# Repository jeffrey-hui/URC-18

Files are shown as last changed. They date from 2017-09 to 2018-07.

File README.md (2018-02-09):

# URC-18

Hello there! Welcome to the URC-18 github repository. Here is where all the URC code for 2018 is see teamr3/URC for 2017.
The file structure of this repo is fairly simple:

| File/Directory | Purpose |
| :--- | ---: |
| rosws | contains all the packages we have written in ros, packages that are deps should either be done with wstool or rosdep |
| scripts | contains various scripts to make things easier |
| microcontroller | contains platformio projects for each microcontroller |
| pcbs | contains PCB eagle design files |

## getting setup

To get setup, do the following:

1. Clone this repository

...Make sure you put it somewhere memorable, you're going to be cd-ing to it a lot.

2. From the *root* of the repo, run `scripts/setup.sh`

...The script will ask you about some things, and might prompt you to install some stuff.
...Once it's done, it'll build everything. If this fails, it probably just means we have some bad code checked in.

3. That's it!

## requirements

- a working ROS install, currently we're using kinetic.

# branches

In order to ensure working code on the master branch, keep new features/packages on their own branches. If you are re-writing something, make a new branch for the rewrite, and
base new packages off of that branch. For example:

```
+-- master
    + -- science-excel
    + -- new-auto
         + -- move_base_config
    + -- ros_control
         + new_arm
         + new_drive
```

---
*Master should always be good working code*
---

When a feature/bugfix is done on a branch, it can be merged to its parent. For example, if `new_arm` in the example was done, it would get merged to `ros_control`. When all of `ros_control` is done, it
gets merged to master. Try and use pull requests for bigger merges, especially when re-writing large portions of existing code.

# documentation

The decision has been made to use readthedocs, the url is r3-urc18.readthedocs.io.
Documentation is in the docs/ folder. Information on how to document is coming soon

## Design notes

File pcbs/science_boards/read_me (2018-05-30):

//TODO:
-Add optocouplers for all digital sensors, refer to main board for optocoupler
and the required passives (attempt to find the surface mount version of the
optocoupler used on the main board)
-Add 7V supply for annemometor
-decoupling capacitors for all supply lines
-bidirectional logic level converter for i2c, refer to battery boards
for how to do this (Ask Gabe if you cant figure it out)
-arbitrary analog and digital inputs
//NOTE:
-1206 series 
-HCPL0500
-Molex Mini Fit Jr.

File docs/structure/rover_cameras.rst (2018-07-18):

=============
rover_cameras
=============

The rover_cameras package contains the launch files and code to handle the rover's cameras.

There is one launch file to launch all the camera nodes. This also contains the camera switcher node.

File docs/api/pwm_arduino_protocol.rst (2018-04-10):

====================
Arduino Protocol (eml_uberdriver)
====================

The eml_uberdriver protocol documentation is now hosted elsewhere due to it being a seperate library.

Find it here: http://r3enamel.readthedocs.io/en/latest

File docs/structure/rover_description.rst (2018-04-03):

=================
rover_description
=================

The rover_description package contains all the urdf related things. It's a quite simple package
There is only one special folder in it, ``urdf``

--------
``urdf``
--------

In here are all the xacro files for the rover urdf. Attachments like the arm or autonomous should be put in separate files and be parametrized
so that different robot configurations are easily modeled.

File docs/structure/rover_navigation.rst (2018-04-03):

================
rover_navigation
================

``rover_navigation`` is our implementation / configuration of a move_base stack.

.. note:
   Although this file does document how to change the auton parameters, for general usage you should probably just start the launch file
   as described in the usage docs.

----------
``config``
----------

The config folder contains all of the yaml configuration for ``move_base``. There are three files in it.

``planner.yaml``
================

``planner.yaml`` contains all of the configuration for the planners (global and local). For documentation on what the parameters in it mean,
see the docs for ``base_local_planner`` and ``navfn``.

``local_costmap.yaml`` and ``global_costmap.yaml``
==================================================

These files contain the configuration for the local and global costmaps respectively. The documentation for them is in the `costmap_2d` package.

---------------------
Internal Launch Files
---------------------

Although the usage documentation only details one launch file, there are a lot of internal ones with more parametrization.

``move_base.launch``
====================

The ``move_base.launch`` file contains the launch spec for starting move_base itself. It contains two useful parameters, located on lines 6 and 7:

.. code-block:: xml
   :lineno-start: 6
        <param name="base_global_planner" value="global_planner/GlobalPlanner" />
        <param name="base_local_planner" value="base_local_planner/TrajectoryPlannerROS" />

This sets the ``base_(global/local)_planner``.

``odometry.launch``
===================

This is one of the most important files in the ``rover_navigation`` package. It contains the sensor fusion configuration. For documentation
on how to configure it, see the documentation for ``robot_localization``.

``visual_odom.launch``
======================

This file contains the parameters (but right now mainly just remappings) for the rtabmap visual odometry.

``rtabmap.launch``
==================

This file contains the parameters for rtabmap's main node. Add mapping parameters here.

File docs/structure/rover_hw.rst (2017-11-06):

========
rover_hw
========

``rover_hw`` is the package which contains the HardwareInterface implementation for our rover. For more information on that, see either the
internal documentation and/or the documentation for ros_control.

This package contains only one file defining the interface, but its structure is important

-----------------------------
Hardware Extension Definition
-----------------------------

Everytime we add a new hardware component with ros_control to the rover, a new hardware_interface "extension" is created in its package.
For example, ``rover_drive`` has its implementation in ``src/drive_hw``. This folder is built into a library, and that library needs to provide
a class with the following methods:

Methods
=======

``init(hardware_interface::RobotHW *hw)``
-----------------------------------------

This method is called to initialize the hardware, as well as register any needed interfaces (e.g. ``JointStateInterface`` ) on the RobotHW instance.

``read()``
----------

This method should *only* update the interfaces with new values from the hardware, like encoders or limit switches.
It is called *before* updating the controllers

``write()``
-----------

This method should only *write* to the hardware with new values from the interfaces. It is called *after* updating the controllers.

-------------------------
``hw_node.cpp`` structure
-------------------------

This file contains the implementation of HardwareInterface. The convention for creating extensions to it was defined above.

For each extension you want to add, you must add the containing package as a dependency in the ``package.xml`` and ``CMakeLists.txt`` file.

In the denoted sections in the file, the declaration of your class and calling of its methods should be added, see how the rover_drive package does it
as an example.

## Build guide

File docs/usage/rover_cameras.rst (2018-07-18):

=============
rover_cameras
=============

The nodes in the ``rover_cameras`` package are designed to manipulate rover camera streams. The launch files are what launch them
to get all the feeds actually running.

-----
Nodes
-----

``image_rotater``
=================

The ``image_rotater`` node takes in one input stream and rotates it by a constant amount.

Topics
------

- ``~image_rotater/image_in`` - image stream to rotate
- ``~image_rotater/image_out`` - published image stream

Parameters
----------

- ``angle`` - angle in degrees to rotate by

``camera_diagnostics``
======================

The ``camera_diagnostics`` node monitors ``/dev/video`` paths and publishes diagnostic information for them.

Parameters
----------

- ``~expected_nums`` - video numbers to monitor

``swapper.py``
==============

Runs and manages ``usb_cam`` nodes to deal with cameras with a ros api. Typically you use the cli to interact with it.

------------
Launch files
------------

The only launch file in `rover_cameras` starts the camera swapper.

---
CLI
---

.. important::
        The cli for camera swapping requires you install the `prompt_toolkit` python package.

The cli (node name ``swapper_cli.py``) allows you to interact with the swapper.
Each camera is just represented as a name and a video device, the node doesn't actually store these things.

The CLI has built in help, (as well as autocomplete) but documentation is also provided here:

Commands
========

``quit``
--------

Quits the CLI.

``load``
--------

Two parameters, first is the camera name, next is the video device (``/dev/videoN``). Optionally takes a parameter, which is the
preffered device to unload if we cannot run this many cameras. Using this parameter allows you to quickly switch cameras.

```
> load belly_cam /dev/video0 head_cam
```
Swaps head_cam with belly_cam

``unload``
----------

Unloads the camera (by name) given to it as a parameter.

``list``
--------

Lists all running cameras by name.

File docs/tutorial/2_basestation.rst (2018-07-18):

=====================
Controlling the rover
=====================

Now that you've started the rover, you need to control it. The first thing you need to do is start the watchdog client.

.. note::
   The watchdog automatically stops the rover if the basestation is not connected for more than 1 second.

To start the watchdog client, use ``$ rosrun rover wclient.py``. 

--------
Drive
--------

Teleoperating the drivetrain is very easy. Start by running ``$ roslaunch rover_teleoperation simple_drive_teleop.launch``. If you get
an error about unable to open joysticks, you may need to find the right joystick device under ``/dev/input/js<N>`` and add ``dev:=/dev/input/js<N>`` to the
end of the command.

The controls are simple (on an xbox style controller):

- left & right stick - tank controls
- dpad up & down - gear up/down (speed levels)

------
Camera
------

Cameras can be viewed using the rqt utility. Adding the image view plugin under visualization allows you to view image topics. To control cameras, you need
to use the camera swapper cli. Information on how it works and the commands it supports can be found at :doc:`../usage/rover_cameras.rst`.

Using rqt, you can view the images by clicking the refresh icon in the image view plugin, then selecting the topic ending with "compressed" and with the name
of the camera you set in the cli.

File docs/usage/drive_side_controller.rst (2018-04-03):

=====================
drive_side_controller
=====================

``drive_side_controller`` is a controller in the ``rover_drive`` package that relays a single velocity command to multiple joints on
one side of the rover. Its pluginlib name is ``rover_drive/DriveSideController``. This controller uses the velocity interface.

----------
Parameters
----------

``joints``
==========

This is the only parameter in ``drive_side_controller``. It is a list and its contents are the joints to use for this side.
Example:

.. code:: yaml

    joints:
        - back_left_wheel
        - front_left_wheel

This would make the controller control the `back_left_wheel` and `front_left_wheel` with the same command.

------
Topics
------

``drive_side_controller/cmd``
=============================

This topic is subscribed to as a Float64 topic containing the current velocity command for all the joints.

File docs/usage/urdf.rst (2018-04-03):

==============
rover_description
==============

--------
``urdf``
--------

Our urdf is contained in the ``rover_description`` package. Various different configurations for it are available (todo: actually add them), which can be
specified with launch file parameters to the ``description.launch`` file. Right now the current configuration parameters are:

<none>

The launch file places the compiled urdf into ``/robot_description`` on the parameter server.

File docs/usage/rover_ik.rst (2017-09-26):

========
rover_ik
========

-----------------------
``ik_joint_controller``
-----------------------

The ``rover_ik::IKJointController`` is a controller in ros_control that does inverse kinematics on a set of joints and feeds the result to a PID loop.
A full usage example can be seen in rover_control.

Parameters
==========

`joints`
--------

This parameter is a list of joints to control, each one should provide an ``EffortJointInterface``

`gains`
-------

Each subparameter in this parameter corresponds to PID gains for a joints, for example:

.. code:: yaml

   gains:
      arm_base_to_post: {p: 7, i: 1, d: 0, i_clamp: 1}

This sets the gains for joint ``arm_base_to_post`` to P = 7, I = 1, D = 0 and I_Clamp = 1.

`base_link` and `tip_link`
--------------------------

This correspond to the *links* at each end of the joint chain, base being the start and tip being the end.

Topics & Services
=================

`controller_name/target`
------------------------

Controller listens on this topic for the target pose of the `tip_link`, as defined in the parameters. The coordinates for this pose
are relative to the ``base_link``. (testing required)

`controller_name/request_position`
----------------------------------

This service can be called to return the current position of the arm as calculated via forward kinematics. Passing this back into
``target`` should cause no effect to the arm.

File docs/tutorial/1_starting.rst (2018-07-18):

==================
Starting the rover
==================

Starting the rover is not a very complicated procedure.
First, you need to ssh into the TX2, then start rover.launch.
This process is detailed below.

----------------
SSH-ing to rover
----------------

To ssh into the rover, use ``$ ssh ubuntu@<ip>``

The IP depends on which TX2 is currently being used. If it is marked on top of the TX2, use it otherwise refer to this table.

======== ===============
TX2 Desc Ip Address
======== ===============
On Rover 192.168.137.213
======== ===============

Once on the rover, navigate to ``~/URC-18``

-------------------------
Starting rover launchfile
-------------------------

First, ensure ros is properly sourced with ``$ source /opt/ros/kinetic/setup.bash``
Next, source the rover's setup file with ``$ source rosws/devel/setup.bash``

Finally, start the rover software with ``roslaunch rover rover.launch``.
To start autonomous nodes, add ``start_auton:=true`` to the end of the previous command.

This procedure will start the rover's software, but to control it from a basestation you need to read on.

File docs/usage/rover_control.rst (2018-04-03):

=============
rover_control
=============

------------
Launch Files
------------

``rover_control.launch``
========================

This launch file is for loading controller parameters and starting ``robot_state_publisher``. It takes two parameters:

- ``use_fake`` - default ``false`` - whether or not to load the fake_controllers file.
- ``controllers`` - default depends on use_fake - which controllers to load by default.

The launch file also starts the :doc:`rover_hw node <rover_hw.rst>` if the ``use_fake`` parameter is set to false.

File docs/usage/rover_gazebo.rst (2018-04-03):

============
rover_gazebo
============

All of the useful functionality in ``rover_gazebo`` is in launch files. Since there is no "real" top-level launch file to refer to,
all of the launch files used to start gazebo have *no parameters*.

------------
Launch files
------------

As explained in the :doc:`structure documentation <../structure/rover_gazebo.rst>`, each world defined there has a launch file corresponding to it.
There are no parameters in these launch files. For all the worlds, see the table under ``worlds`` in that file.

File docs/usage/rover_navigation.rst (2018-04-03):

================
rover_navigation
================

To use the rover_navigation package to start a working move_base stack, run the ``rover_navigation.launch``. That's it.
This launch file will start the entirety of the navigation stack. To use move_base, see its documentation. When gps_goal and friends
are implemented they'll be put here.

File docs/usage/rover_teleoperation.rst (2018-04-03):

===================
rover_teleoperation
===================

------------
Launch Files
------------

``simple_drive_teleop.launch``
==============================

This launch file starts a ``joy`` node and a drive teleoperation node.
It takes one parameter, ``dev`` which is the joystick to open.

.. important::

   The teleoperation node expects an XBox controller (or compatible), otherwise the mappings will not be correct

-----
Nodes
-----

``arm_ik_joy_teleop``
=================

This node (currently without a launch file) is for commanding the :doc:`ik_joint_controller <rover_ik.rst>` with a joystick.

It listens on the ``joy`` topic for joystick input and outputs to the ``arm_ik_controller/target`` topic.

``simple_drive_joy_node``
=========================

This node commands drive from a diff drive joystick.

It listens on the ``joy`` topic for joystick input and outputs to the ``/left_wheels_controller/cmd`` and ``/right_wheels_controller/cmd`` topics.

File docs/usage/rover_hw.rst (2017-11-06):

========
rover_hw
========

The rover_hw package contains the hardware interface and controller node.

-------------
``rover_hw_node``
-------------

``rover_hw_node`` is the node that runs all the controllers. It takes no parameters, as parametrization of hardware interfaces
should be done as compile time constants.

Running this node is enough to start a controller manager with proper hardware interfaces.

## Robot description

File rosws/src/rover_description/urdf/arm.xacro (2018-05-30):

<?xml version="1.0" ?>
<robot xmlns:xacro="http://www.ros.org/wiki/xacro">
    <xacro:macro name="arm_z_pole" params="suffix x">
        <link name="arm_z_pole_${suffix}">
            <inertial>
                <mass value="0.22"/>
                <inertia ixx="0.0183532929708" ixy="0" ixz="0" iyy="0.0183532929708" iyz="0" izz="3.9919275e-05"/>
            </inertial>
            <visual>
                <origin xyz="0 0 0.485" rpy="0 0 0"/>
                <material name="Red"/>
                <geometry>
                    <cylinder length="0.97" radius="0.01905"/>
                </geometry>
            </visual>
            <collision>
                <origin xyz="0 0 0.485" rpy="0 0 0"/>
                <geometry>
                    <cylinder length="0.97" radius="0.01905"/>
                </geometry>
            </collision>
        </link>

        <joint name="base_link_to_arm_z_pole_${suffix}" type="fixed">
            <parent link="base_link"/>
            <child link="arm_z_pole_${suffix}"/>
            <origin xyz="${x} 0 0.1"/>
        </joint>
    </xacro:macro>

    <xacro:arm_z_pole x="0.09" suffix="back"/>
    <xacro:arm_z_pole x="0.24" suffix="front"/>

    <link name="arm_z_pole_endcap">
        <inertial>
            <mass value="0.39"/>
            <inertia ixx="0.0001105" ixy="0" ixz="0" iyy="0.00132925" iyz="0" izz="0.00138125"/>
        </inertial>
        <visual>
            <origin xyz="0.075 0 0.03" rpy="0 0 0"/>
            <material name="Yellow"/>
            <geometry>
                <box size="0.2 0.05 0.03"/>
            </geometry>
        </visual>
        <collision>
            <origin xyz="0.075 0 0.03" rpy="0 0 0"/>
            <geometry>
                <box size="0.2 0.05 0.03"/>
            </geometry>
        </collision>
    </link>

    <joint name="arm_z_pole_to_arm_z_pole_endcap" type="fixed">
        <parent link="arm_z_pole_back"/>
        <child link="arm_z_pole_endcap"/>
        <origin xyz="0 0 0.97"/>
    </joint>

    <link name="arm_slider_unit">
        <inertial>
            <mass value="1.26"/>
            <inertia ixx="0.002625" ixy="0" ixz="0" iyy="0.021777" iyz="0" izz="0.019677"/>
        </inertial>
        <visual>
            <material name="Green"/>
            <origin xyz="0.19 0 0.075" rpy="0 0 0"/>
            <geometry>
                <box size="0.43 0.05 0.15"/>
            </geometry>
        </visual>
        <collision>
            <origin xyz="0.19 0 0.075" rpy="0 0 0"/>
            <geometry>
                <box size="0.43 0.05 0.15"/>
            </geometry>
        </collision>
    </link>

    <xacro:linkColor link="arm_slider_unit" mat="Gazebo/Blue" />

    <joint name="arm_slide_pole_to_arm_slider_unit" type="prismatic">
        <parent link="arm_z_pole_back"/>
        <child link="arm_slider_unit"/>
        <axis xyz="0 0 1"/>
        <origin xyz="0 0 0" rpy="0 0 0"/>
        <limit effort="2000" velocity="1" lower="0" upper="0.895"/>
    </joint>

    <link name="arm_xy_pole">
        <inertial>
            <mass value="0.32"/>
            <inertia ixx="0.00366316666667" ixy="0" ixz="0" iyy="0.00366316666667" iyz="0" izz="2.5e-05"/>
        </inertial>
        <collision>
            <origin xyz="0 0 -0.185" rpy="0 0 0"/>
            <geometry>
                <cylinder length="0.37" radius="0.0125"/>
            </geometry>
        </collision>
        <visual>
            <material name="White"/>
            <origin xyz="0 0 -0.185" rpy="0 0 0"/>
            <geometry>
                <cylinder length="0.37" radius="0.0125"/>
            </geometry>
        </visual>
    </link>

    <joint name="arm_slider_unit_to_arm_xy_pole" type="revolute">
        <origin xyz="0.379 0 0" rpy="0 0 0"/>
        <axis xyz="0 0 1"/>
        <child link="arm_xy_pole"/>
        <parent link="arm_slider_unit"/>
        <limit effort="3.7" velocity="3.875" lower="-2.09" upper="2.09"/>
    </joint>

    <link name="arm_inner">
        <inertial>
            <mass value="0.46"/>
            <inertia ixx="0.000155058333333" ixy="0" ixz="0" iyy="0.00252846666667" iyz="0" izz="0.00257281833333"/>
        </inertial>
        <collision>
            <origin xyz="0.103 0 -0.019" rpy="0 0 0"/>
            <geometry>
                <box size="0.254 0.051 0.038"/>
            </geometry>
        </collision>
        <visual>
            <material name="Blue"/>
            <origin xyz="0.103 0 -0.019" rpy="0 0 0"/>
            <geometry>
                <box size="0.254 0.051 0.038"/>
            </geometry>
        </visual>
    </link>

    <xacro:linkColor link="arm_inner" mat="Gazebo/Red" />

    <joint name="arm_xy_pole_to_arm_inner" type="fixed">
        <child link="arm_inner"/>
        <parent link="arm_xy_pole"/>
        <origin xyz="0 0 -0.37"/>
    </joint>

    <transmission name="arm_slide_trans">
        <type>transmission_interface/SimpleTransmission</type>
        <joint name="arm_slide_pole_to_arm_slider_unit">
            <hardwareInterface>hardware_interface/EffortJointInterface</hardwareInterface>
        </joint>
        <actuator name="arm_slide_motor">
            <mechanicalReduction>1</mechanicalReduction>
        </actuator>
    </transmission>

    <transmission name="arm_inner_xy_trans">
        <type>transmission_interface/SimpleTransmission</type>
        <joint name="arm_slider_unit_to_arm_xy_pole">
            <hardwareInterface>hardware_interface/EffortJointInterface</hardwareInterface>
        </joint>
        <actuator name="arm_xy_inner_motor">
            <mechanicalReduction>1</mechanicalReduction>
        </actuator>
    </transmission>

    <xacro:property name="gripper_type" value="$(arg gripper_type)" />
    <xacro:if value="${gripper_type != 'no_gripper'}">
        <xacro:include filename="grippers/$(arg gripper_type).xacro"/>
    </xacro:if>
</robot>

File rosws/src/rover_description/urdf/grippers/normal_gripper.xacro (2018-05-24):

<?xml version="1.0" ?>
<robot xmlns:xacro="http://www.ros.org/wiki/xacro">
    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

    <link name="arm_outer">
        <inertial>
            <mass value="0.12" />
            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
        </inertial>
        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
    </link>

    <link name="grip_tilt">
        <inertial>
            <mass value="0.2" />
            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
        </inertial>
        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
    </link>

    <link name="grip_spin">
        <inertial>
            <mass value="0.05" />
            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
        </inertial>
        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
    </link>

    <joint name="arm_outer_to_grip_tilt" type="revolute">
        <parent link="arm_outer" />
        <child link="grip_tilt" />
        <origin xyz="0.225 0 0" rpy="0 0 0" />
        <axis xyz="0 1 0" />
        <limit upper="1.57" lower="-1.04" effort="300" velocity="0.3"/>
    </joint>

    <joint name="arm_inner_to_arm_outer" type="revolute">
        <parent link="arm_inner" />
        <child link="arm_outer" />
        <origin xyz="0.217 0 -0.038" rpy="0 0 0" />
        <axis xyz="0 0 1" />
        <limit upper="1.57" lower="-1.57" effort="500" velocity="0.8" />
    </joint>

    <joint name="grip_tilt_to_grip_spin" type="revolute">
        <parent link="grip_tilt" />
        <child link="grip_spin" />
        <origin xyz="0.09 0 -0.0065" rpy="0 0 0" />
        <axis xyz="0 0 1" />
        <limit upper="12.4" lower="-12.4" effort="400" velocity="1" />
    </joint>

    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

    <xacro:macro name="tooth" params="offsetx offsety rotang suffix">
        <link name="tooth_${suffix}_upper">
            <inertial>
                <mass value="0.3" />
                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
            </inertial>
            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
        </link>

        <link name="tooth_${suffix}_lower">
            <inertial>
                <mass value="0.3" />
                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
            </inertial>
            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
        </link>

        <joint name="grip_spin_to_tooth_${suffix}" type="revolute">
            <parent link="grip_spin" />
            <child link="tooth_${suffix}_upper" />
            <origin xyz="${offsetx} ${offsety} -0.006" rpy="0 0 ${rotang}" />
            <limit upper="1.16" lower="0" effort="400" velocity="0.3" />
            <axis xyz="0 1 0" />
        </joint>

        <joint name="tooth_${suffix}_upper_to_lower" type="fixed">
            <parent link="tooth_${suffix}_upper" />
            <child link="tooth_${suffix}_lower" />
            <origin xyz="0.05 0 -0.005" rpy="0 0.69 0" />
        </joint>

        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

    </xacro:macro>

    <xacro:tooth offsetx="0.0194" offsety="0.0057" rotang="0" suffix="front" />
    <xacro:tooth offsetx="0.0057" offsety="0.0194" rotang="1.57" suffix="left" />
    <xacro:tooth offsetx="-0.0194" offsety="0.0057" rotang="3.14" suffix="rear" />
    <xacro:tooth offsetx="-0.0057" offsety="-0.0194" rotang="4.71" suffix="right" />
</robot>

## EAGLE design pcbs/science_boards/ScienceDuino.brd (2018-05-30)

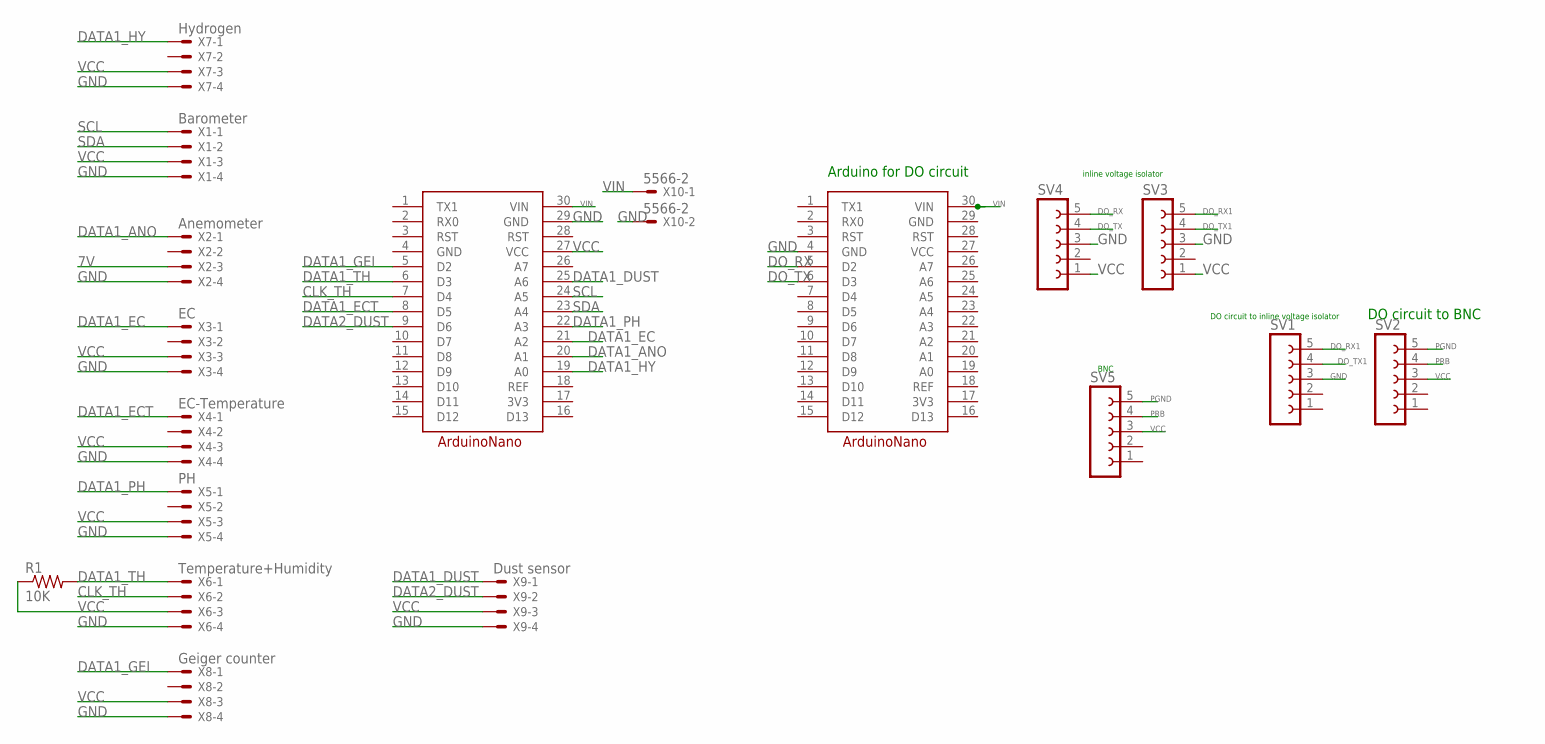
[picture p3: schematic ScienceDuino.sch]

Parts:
A1, A2: ARDUINONANO
R1: 10K; 0204/5
SV1, SV2, SV3, SV4, SV5: FE05-1
X1: Barometer; 5566-4
X2: Anemometer; 5566-4
X3: EC; 5566-4
X4: EC-Temperature; 5566-4
X5: PH; 5566-4
X6: Temperature+Humidity; 5566-4
X7: Hydrogen; 5566-4
X8: Geiger counter; 5566-4
X9: Dust sensor; 5566-4
X10: 5566-2

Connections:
3V3: A1.17 (3V3), A2.17 (3V3)
7V: X2.3
CLK_TH: A1.7 (D4), X6.2
DATA1_ANO: A1.20 (A1), X2.1
DATA1_DUST: A1.25 (A6), X9.1
DATA1_EC: A1.21 (A2), X3.1
DATA1_ECT: A1.8 (D5), X4.1
DATA1_GEI: A1.5 (D2), X8.1
DATA1_HY: A1.19 (A0), X7.1
DATA1_PH: A1.22 (A3), X5.1
DATA1_TH: A1.6 (D3), R1.2, X6.1
DATA2_DUST: A1.9 (D6), X9.2
DO_RX: A2.5 (D2), SV4.5
DO_RX1: SV1.5, SV3.5
DO_TX: A2.6 (D3), SV4.4
DO_TX1: SV1.4, SV3.4
GND: A1.4 (GND), A1.29 (GND), A2.4 (GND), A2.29 (GND), SV1.3, SV3.3, SV4.3, X1.4, X2.4, X3.4, X4.4, X5.4, X6.4, X7.4, X8.4, X9.4, X10.2
PGND: SV2.5, SV5.5
PRB: SV2.4, SV5.4
REF: A1.18 (REF), A2.18 (REF)
SCL: A1.24 (A5), X1.1
SDA: A1.23 (A4), X1.2
VCC: A1.27 (VCC), A2.27 (VCC), R1.1, SV2.3, SV3.1, SV4.1, SV5.3, X1.3, X3.3, X4.3, X5.3, X6.3, X7.3, X8.3, X9.3
VIN: A1.30 (VIN), A2.30 (VIN), X10.1

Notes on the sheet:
DO circuit to BNC
Arduino for DO circuit
DO circuit to inline voltage isolator
BNC
inline voltage isolator

Board: 2 copper layers, 18 parts (0 on the bottom side), 23 nets, no tracks yet.

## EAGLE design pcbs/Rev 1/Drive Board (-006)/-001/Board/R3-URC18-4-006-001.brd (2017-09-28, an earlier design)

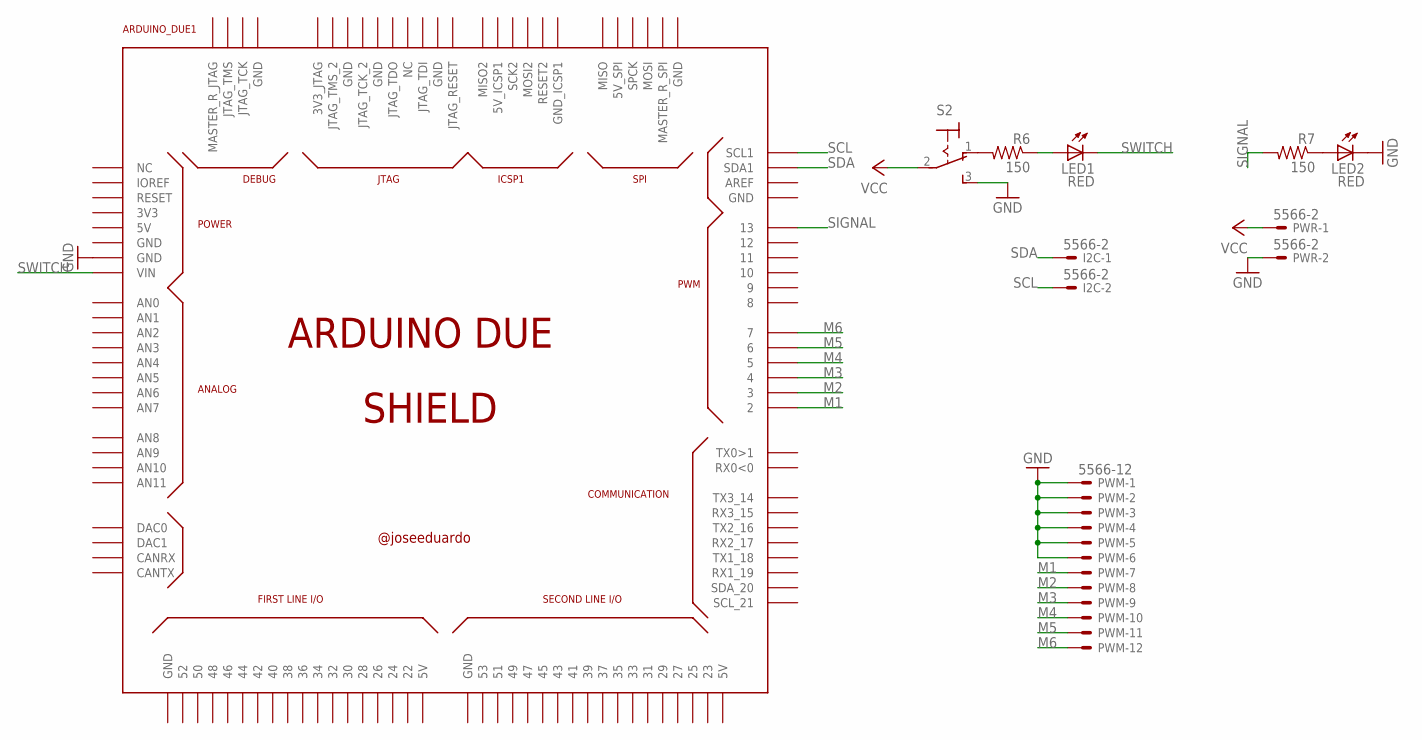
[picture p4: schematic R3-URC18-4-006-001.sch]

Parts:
ARDUINO_DUE1: ARDUINO_DUE_SHIELD
I2C: 5566-2
LED1, LED2: RED; LED5MM
PWM: 5566-12
PWR: 5566-2
R6, R7: 150; 0207/10
S2: M9040P

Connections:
GND: ARDUINO_DUE1.GND_1 (GND), LED2.K (C), PWM.1, PWM.2, PWM.3, PWM.4, PWM.5, PWM.6, PWR.2, S2.3 (S)
M1: ARDUINO_DUE1.2, PWM.7
M2: ARDUINO_DUE1.3, PWM.8
M3: ARDUINO_DUE1.4, PWM.9
M4: ARDUINO_DUE1.5, PWM.10
M5: ARDUINO_DUE1.6, PWM.11
M6: ARDUINO_DUE1.7, PWM.12
unnamed: R6.2, S2.1 (O)
unnamed: LED1.A, R6.1
unnamed: LED2.A, R7.1
SCL: ARDUINO_DUE1.SCL1, I2C.2
SDA: ARDUINO_DUE1.SDA1, I2C.1
SIGNAL: ARDUINO_DUE1.13, R7.2
SWITCH: ARDUINO_DUE1.VIN, LED1.K (C)
VCC: PWR.1, S2.2

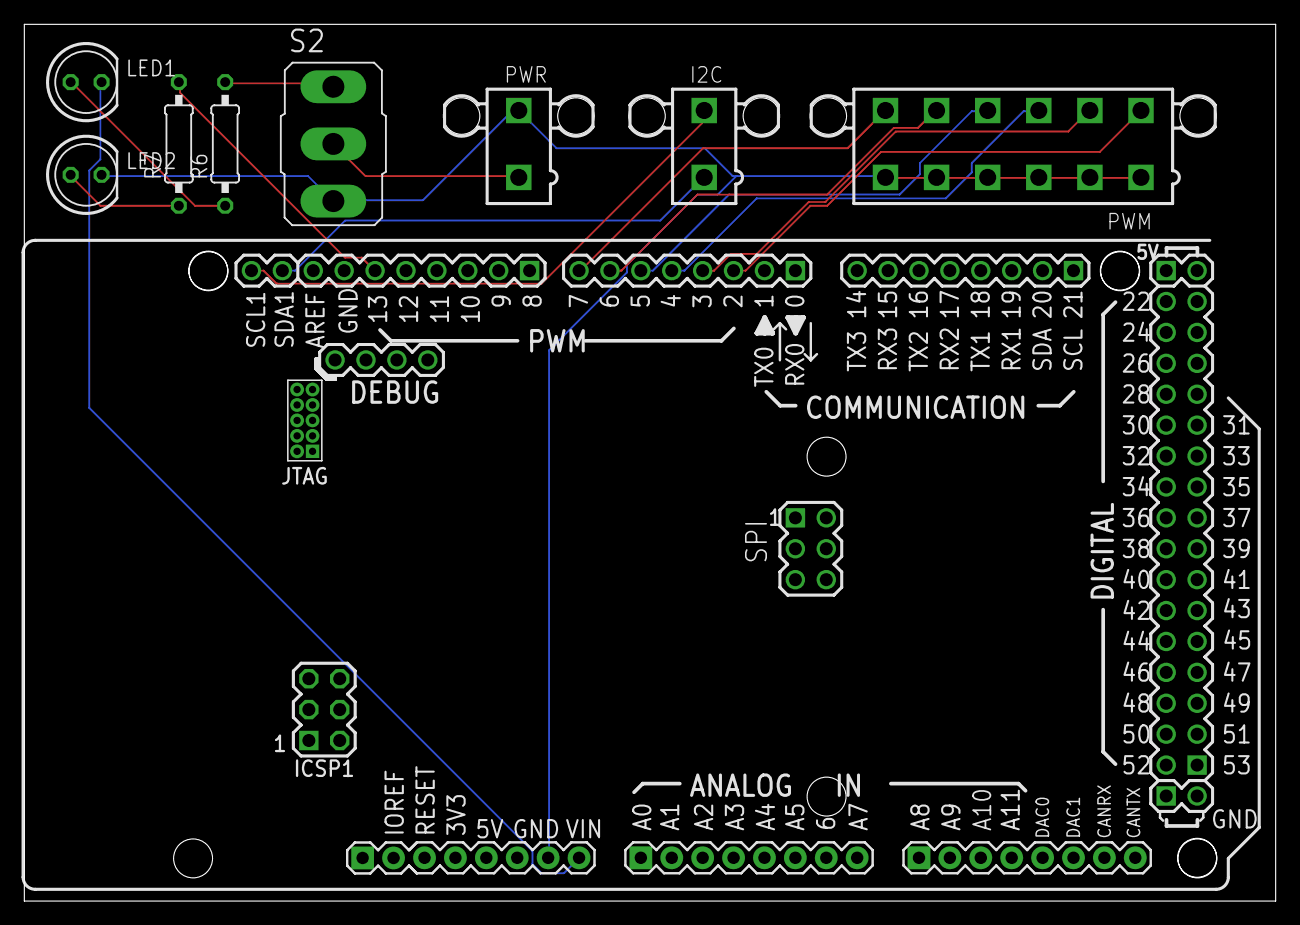
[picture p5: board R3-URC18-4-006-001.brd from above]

Board: 2 copper layers, 102.8 x 72.1 mm, 9 parts (0 on the bottom side), 15 nets.

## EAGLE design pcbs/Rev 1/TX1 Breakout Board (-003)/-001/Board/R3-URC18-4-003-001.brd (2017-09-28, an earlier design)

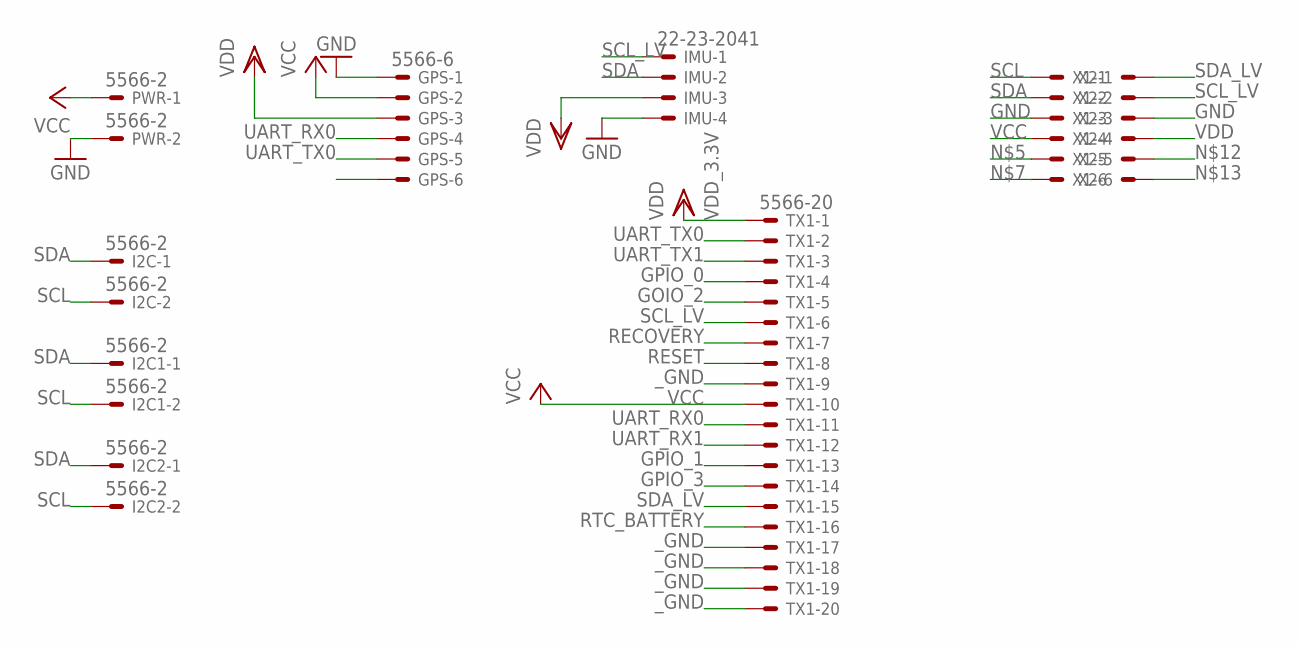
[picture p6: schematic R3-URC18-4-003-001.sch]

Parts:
GPS: 5566-6
I2C, I2C1, I2C2: 5566-2
IMU: 22-23-2041
PWR: 5566-2
TX1: 5566-20
X1, X2: 22-23-2061

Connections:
GND: GPS.1, IMU.4, PWR.2, X1.3, X2.3
GOIO_2: TX1.5
GPIO_0: TX1.4
GPIO_1: TX1.13
GPIO_3: TX1.14
RECOVERY: TX1.7
RESET: TX1.8
RTC_BATTERY: TX1.16
SCL: I2C.2, I2C1.2, I2C2.2, X1.1
SCL_LV: IMU.1, TX1.6, X2.2
SDA: I2C.1, I2C1.1, I2C2.1, IMU.2, X1.2
SDA_LV: TX1.15, X2.1
UART_RX0: GPS.4, TX1.11
UART_RX1: TX1.12
UART_TX0: GPS.5, TX1.2
UART_TX1: TX1.3
VCC: GPS.2, PWR.1, TX1.10, X1.4
VDD: GPS.3, IMU.3, X2.4
VDD_3.3V: TX1.1
_GND: TX1.9, TX1.17, TX1.18, TX1.19, TX1.20

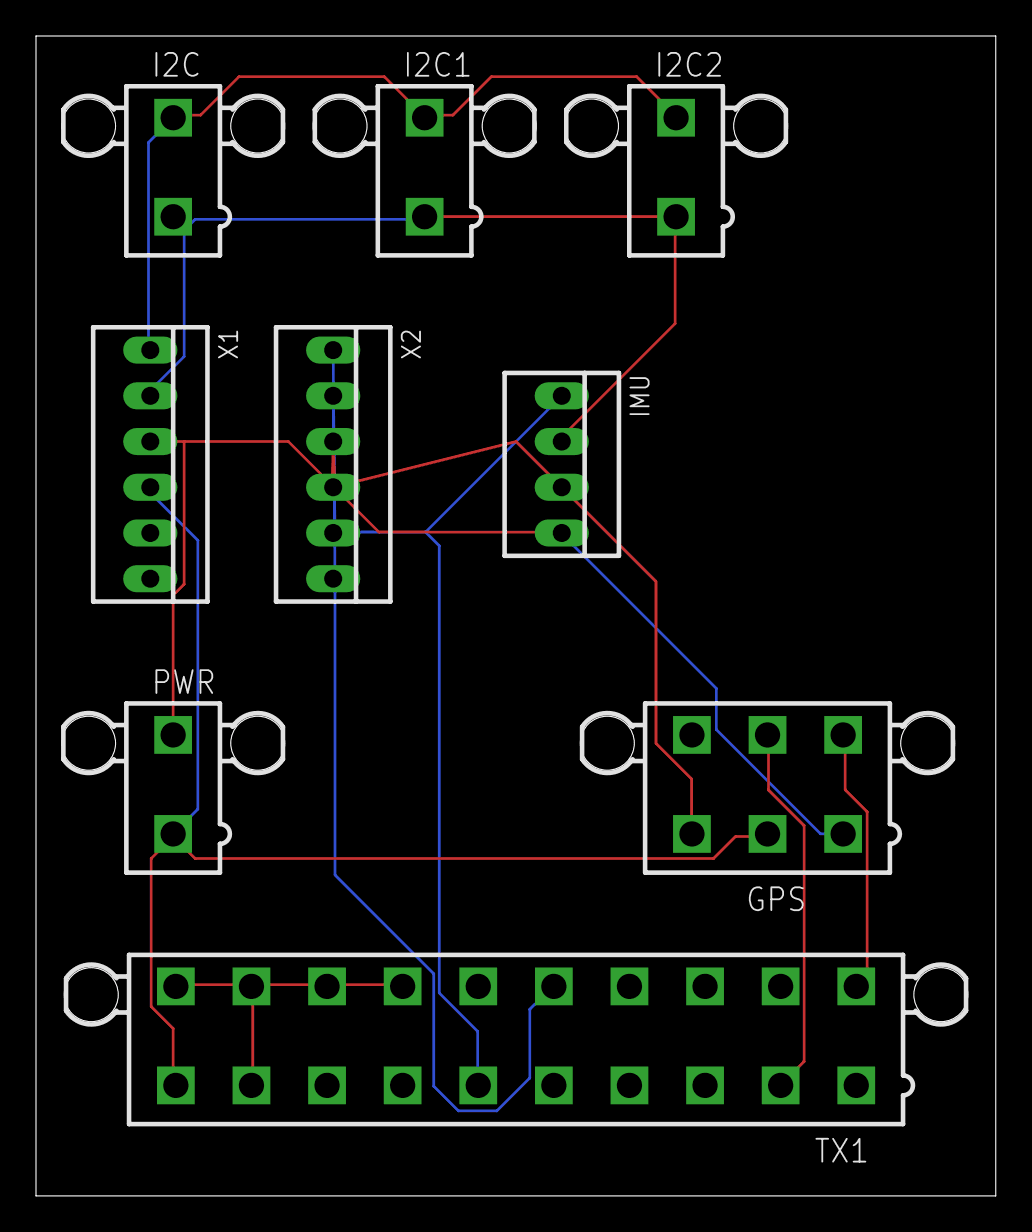
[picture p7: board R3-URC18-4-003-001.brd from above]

Board: 2 copper layers, 53.3 x 64.4 mm, 9 parts (0 on the bottom side), 10 nets.

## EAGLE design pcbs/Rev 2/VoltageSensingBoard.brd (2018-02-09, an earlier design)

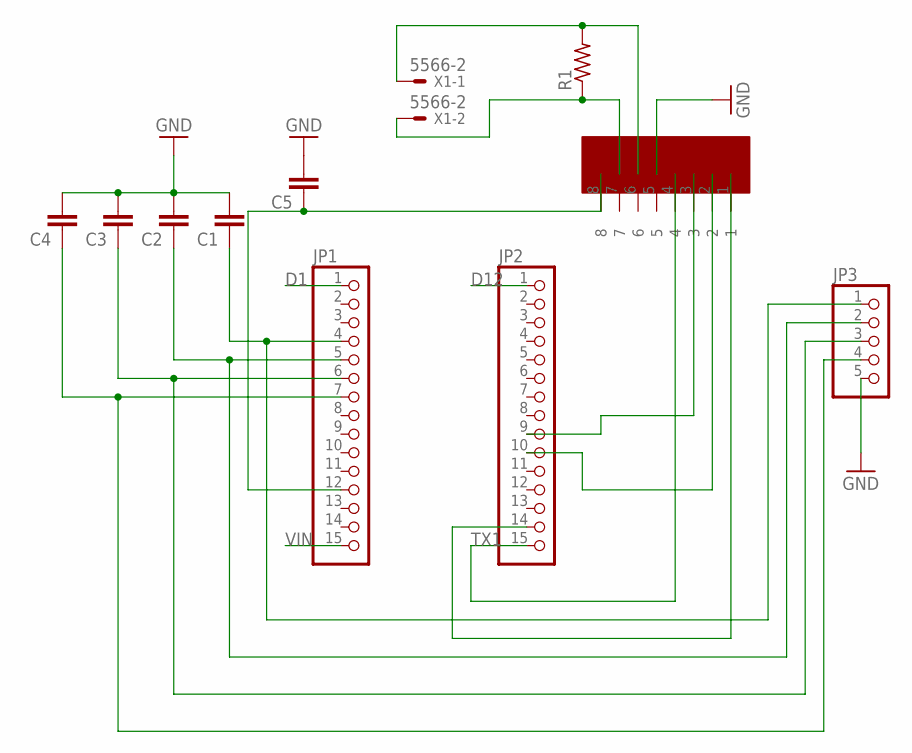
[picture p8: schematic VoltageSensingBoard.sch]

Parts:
C1, C2, C3, C4, C5: C5/2.5; C5B2.5
JP1, JP2: PINHD-1X15; 1X15
JP3: PINHD-1X5; 1X05
R1: R-US_0204/7; 0204/7
U$1: THVD1550; SO08
X1: 5566-2

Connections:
D1: JP1.1
D12: JP2.1
GND: C1.2, C2.2, C3.2, C4.2, C5.2, JP3.5, U$1.5
unnamed: C1.1, JP1.4, JP3.1
unnamed: C3.1, JP1.6, JP3.3
unnamed: C4.1, JP1.7, JP3.4
unnamed: R1.2, U$1.6, X1.1
unnamed: R1.1, U$1.7, X1.2
unnamed: C2.1, JP1.5, JP3.2
unnamed: C5.1, JP1.12, U$1.8
unnamed: JP2.10, U$1.2
unnamed: JP2.14, U$1.1
unnamed: JP2.9, U$1.3
TX1: JP2.15, U$1.4
VIN: JP1.15

Board: 2 copper layers, 11 parts (0 on the bottom side), 12 nets, no tracks yet.

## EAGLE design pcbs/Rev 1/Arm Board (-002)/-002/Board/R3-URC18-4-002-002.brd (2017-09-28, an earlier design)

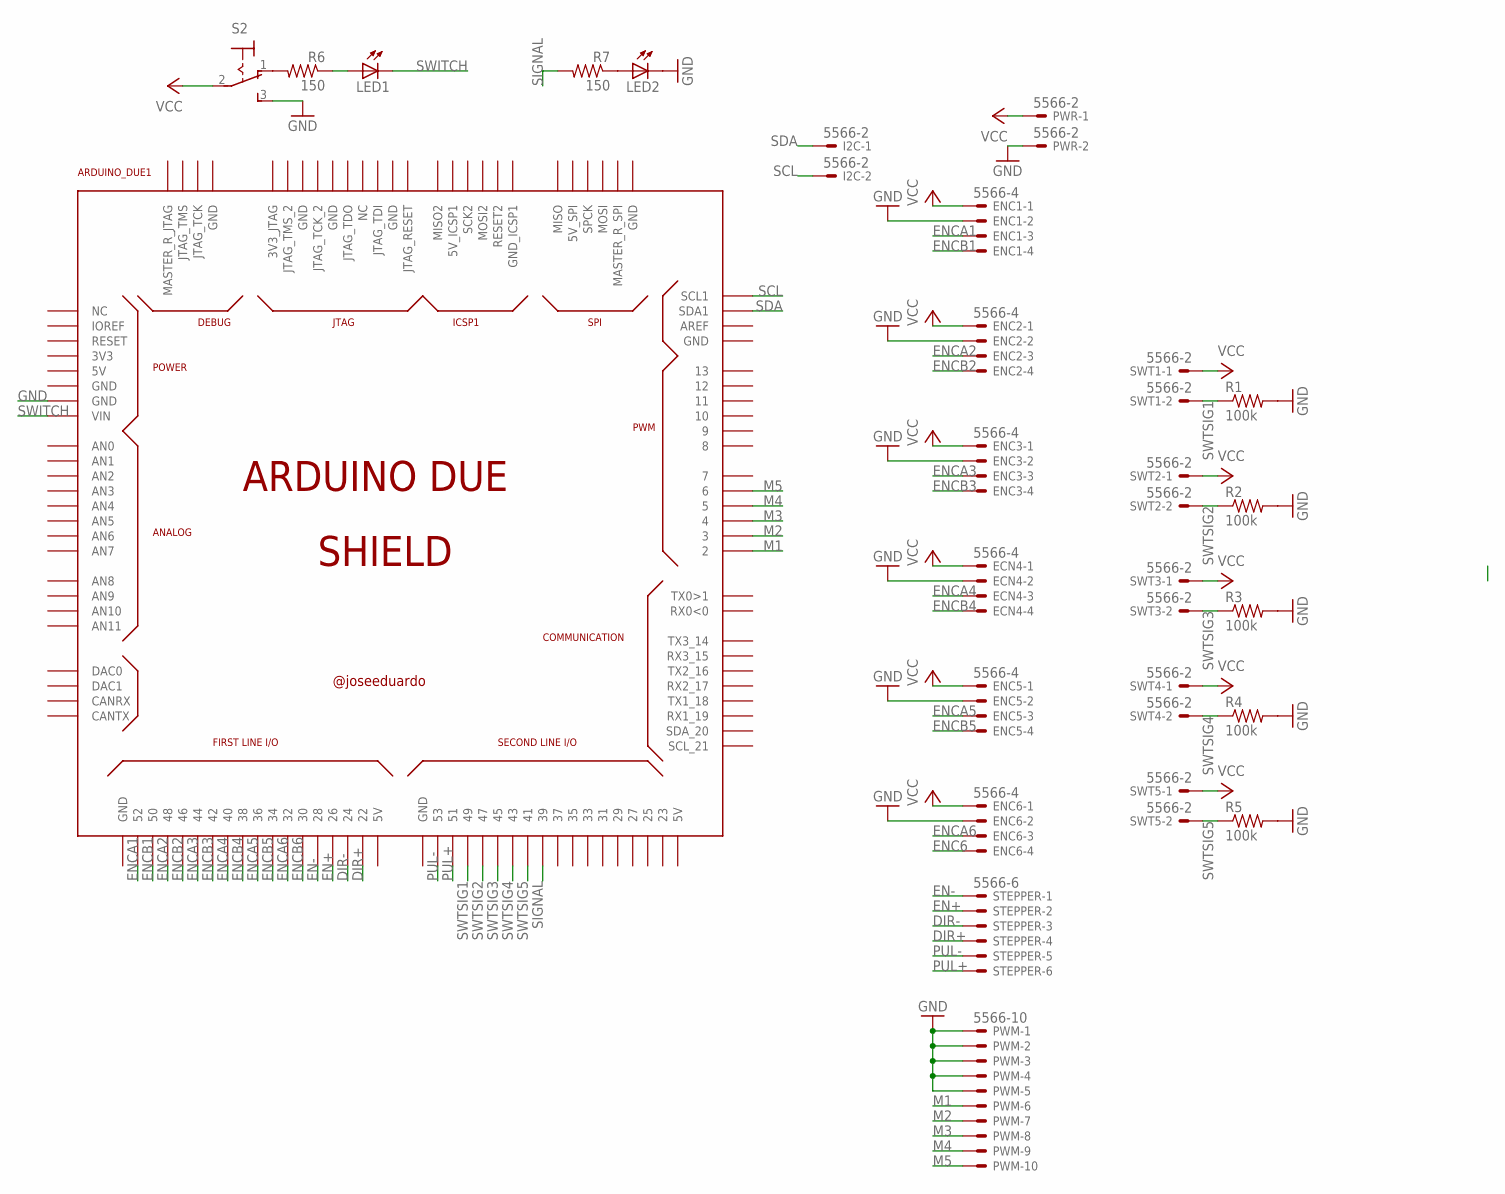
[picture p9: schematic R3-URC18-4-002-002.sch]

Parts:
ARDUINO_DUE1: ARDUINO_DUE_SHIELD
ECN4: 5566-4
ENC1, ENC2, ENC3, ENC5, ENC6: 5566-4
I2C: 5566-2
LED1, LED2: LED5MM
PWM: 5566-10
PWR: 5566-2
R1, R2, R3, R4, R5: 100k; 0207/10
R6, R7: 150; 0207/10
S2: M9040P
STEPPER: 5566-6
SWT1, SWT2, SWT3, SWT4, SWT5: 5566-2

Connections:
DIR+: ARDUINO_DUE1.22, STEPPER.4
DIR-: ARDUINO_DUE1.24, STEPPER.3
EN+: ARDUINO_DUE1.26, STEPPER.2
EN-: ARDUINO_DUE1.28, STEPPER.1
ENC6: ENC6.4
ENCA1: ARDUINO_DUE1.52, ENC1.3
ENCA2: ARDUINO_DUE1.48, ENC2.3
ENCA3: ARDUINO_DUE1.44, ENC3.3
ENCA4: ARDUINO_DUE1.40, ECN4.3
ENCA5: ARDUINO_DUE1.36, ENC5.3
ENCA6: ARDUINO_DUE1.32, ENC6.3
ENCB1: ARDUINO_DUE1.50, ENC1.4
ENCB2: ARDUINO_DUE1.46, ENC2.4
ENCB3: ARDUINO_DUE1.42, ENC3.4
ENCB4: ARDUINO_DUE1.38, ECN4.4
ENCB5: ARDUINO_DUE1.34, ENC5.4
ENCB6: ARDUINO_DUE1.30
GND: ARDUINO_DUE1.GND_1 (GND), ECN4.2, ENC1.2, ENC2.2, ENC3.2, ENC5.2, ENC6.2, LED2.K (C), PWM.1, PWM.2, PWM.3, PWM.4, PWM.5, PWR.2, R1.2, R2.2, R3.2, R4.2, R5.2, S2.3 (S)
M1: ARDUINO_DUE1.2, PWM.6
M2: ARDUINO_DUE1.3, PWM.7
M3: ARDUINO_DUE1.4, PWM.8
M4: ARDUINO_DUE1.5, PWM.9
M5: ARDUINO_DUE1.6, PWM.10
unnamed: R6.2, S2.1 (O)
unnamed: LED1.A, R6.1
unnamed: LED2.A, R7.1
PUL+: ARDUINO_DUE1.51, STEPPER.6
PUL-: ARDUINO_DUE1.53, STEPPER.5
SCL: ARDUINO_DUE1.SCL1, I2C.2
SDA: ARDUINO_DUE1.SDA1, I2C.1
SIGNAL: ARDUINO_DUE1.39, R7.2
SWITCH: ARDUINO_DUE1.VIN, LED1.K (C)
SWTSIG1: ARDUINO_DUE1.49, R1.1, SWT1.2
SWTSIG2: ARDUINO_DUE1.47, R2.1, SWT2.2
SWTSIG3: ARDUINO_DUE1.45, R3.1, SWT3.2
SWTSIG4: ARDUINO_DUE1.43, R4.1, SWT4.2
SWTSIG5: ARDUINO_DUE1.41, R5.1, SWT5.2
VCC: ECN4.1, ENC1.1, ENC2.1, ENC3.1, ENC5.1, ENC6.1, PWR.1, S2.2, SWT1.1, SWT2.1, SWT3.1, SWT4.1, SWT5.1

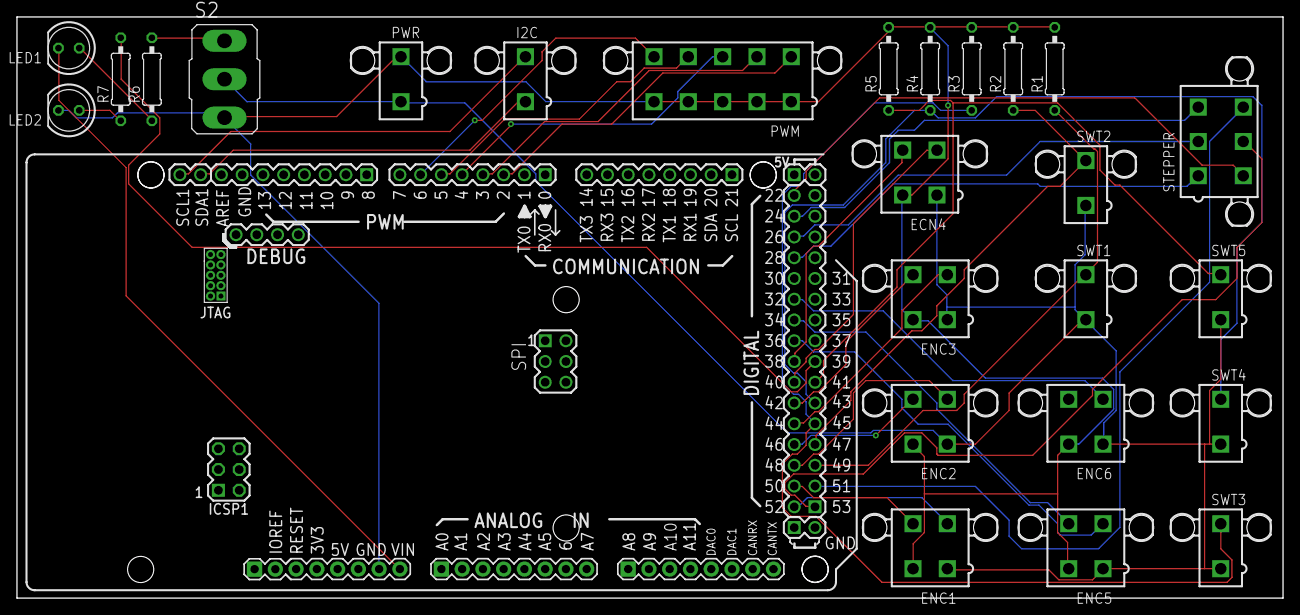
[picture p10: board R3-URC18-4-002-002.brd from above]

Board: 2 copper layers, 154.9 x 71.1 mm, 26 parts (0 on the bottom side), 36 nets.

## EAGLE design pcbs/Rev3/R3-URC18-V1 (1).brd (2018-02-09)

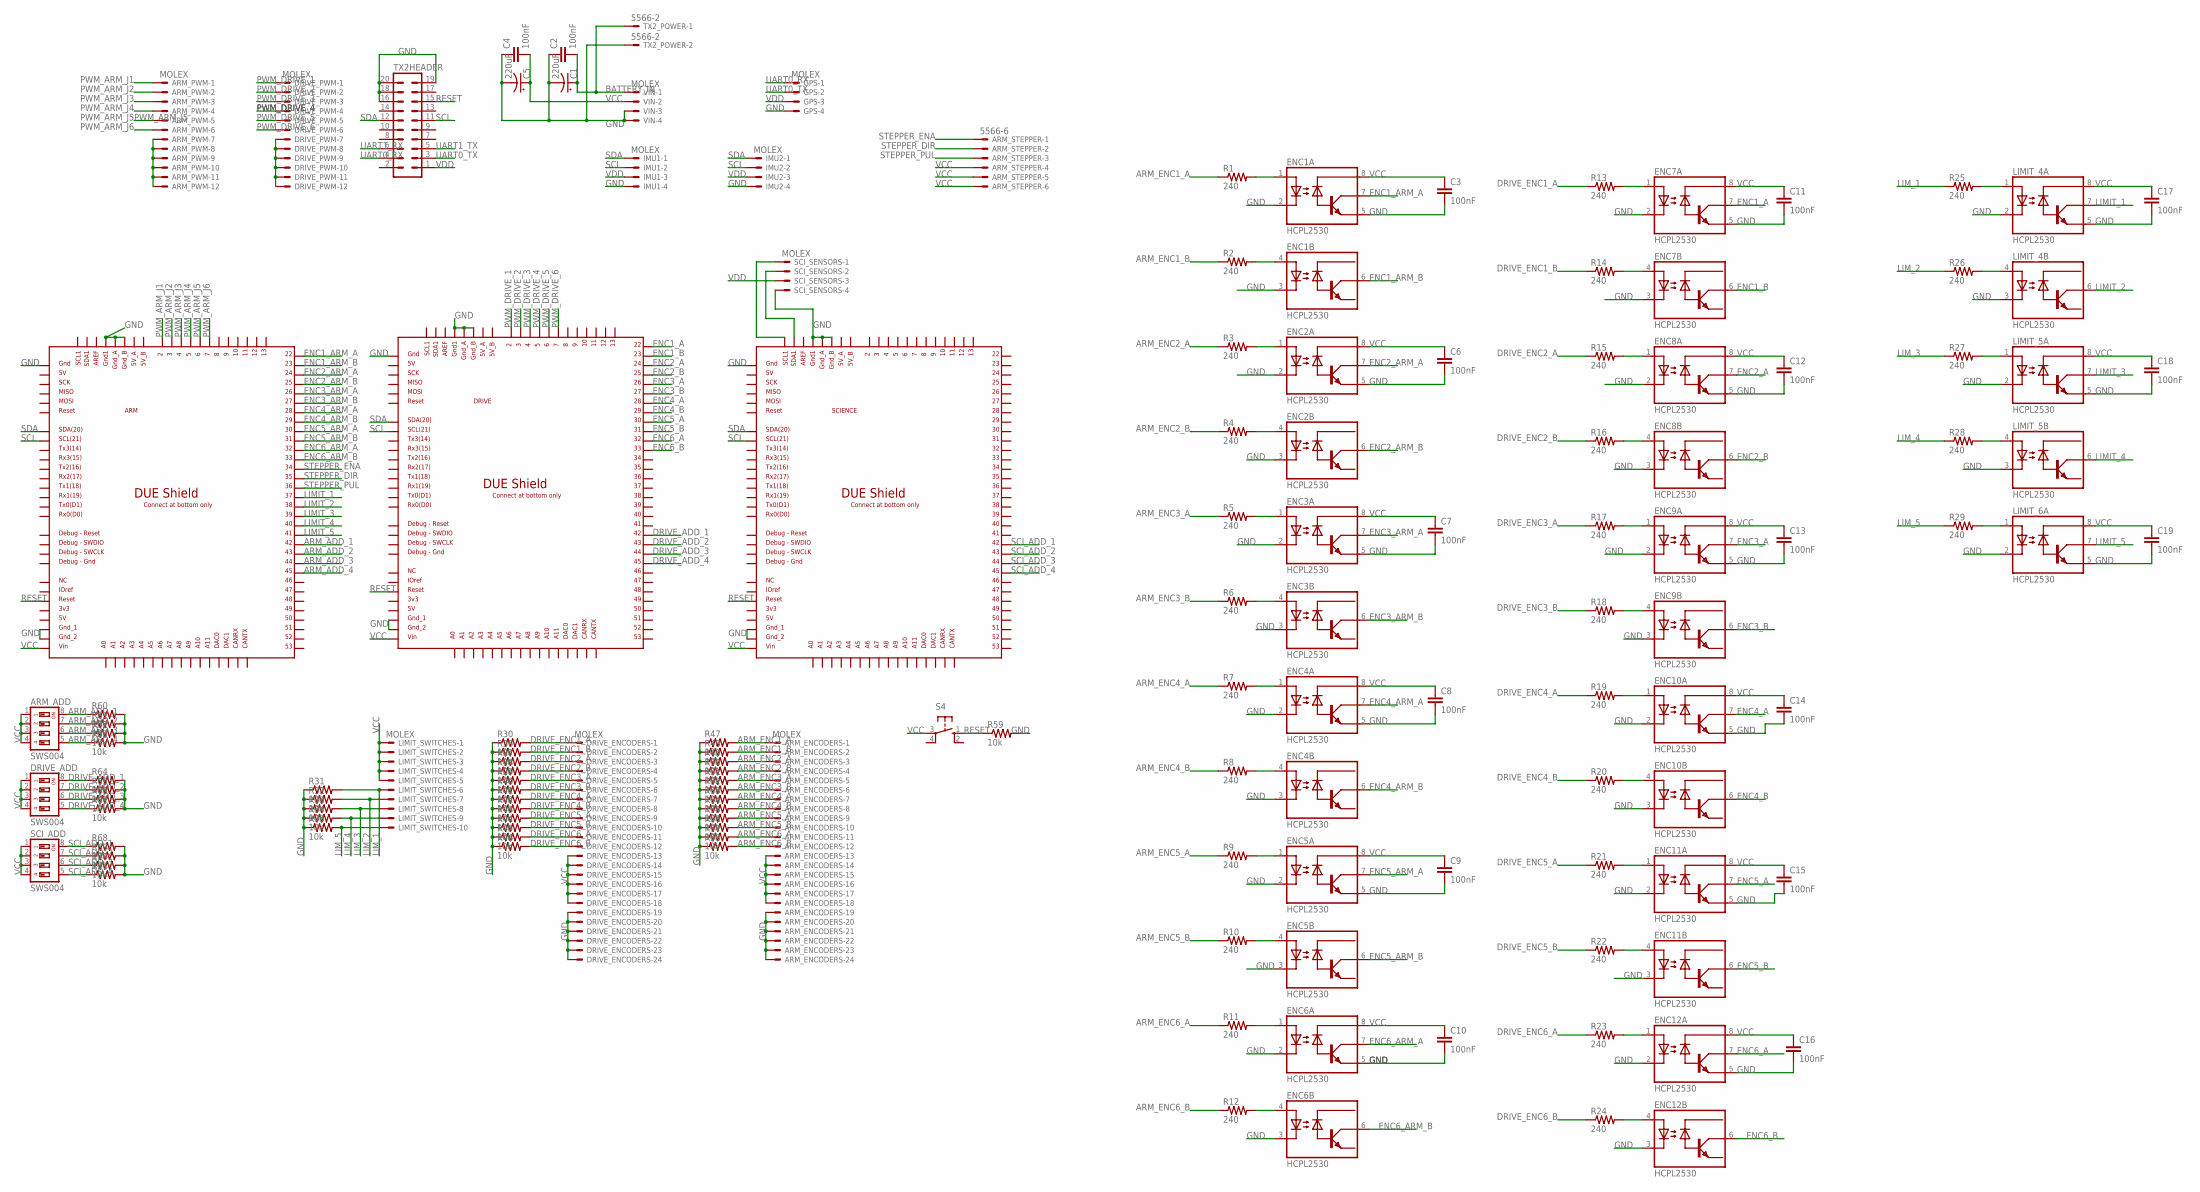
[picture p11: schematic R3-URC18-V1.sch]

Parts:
ARM: DUE(BOTTOMONLY)
ARM_ADD: SWS004; SMS-004
ARM_ENCODERS: MOLEX; 5566-24
ARM_PWM: MOLEX; 5566-12
ARM_STEPPER: 5566-6
C1, C5: 220uF; E7,5-18
C2, C3, C4, C6, C7, C8, C9, C10, C11, C12, C13, C14, C15, C16, C17, C18, C19: 100nF; C2.5-5
DRIVE: DUE(BOTTOMONLY)
DRIVE_ADD: SWS004; SMS-004
DRIVE_ENCODERS: MOLEX; 5566-24
DRIVE_PWM: MOLEX; 5566-12
ENC1, ENC2, ENC3, ENC4, ENC5, ENC6, ENC7, ENC8, ENC9, ENC10, ENC11, ENC12: HCPL2530; DIL08
GPS: MOLEX; 5566-4
IMU1, IMU2: MOLEX; 5566-4
LIMIT_4, LIMIT_5, LIMIT_6: HCPL2530; DIL08
LIMIT_SWITCHES: MOLEX; 5566-10
R1, R2, R3, R4, R5, R6, R7, R8, R9, R10, R11, R12, R13, R14, R15, R16, R17, R18, R19, R20, R21, R22, R23, R24, R25, R26, R27, R28, R29: 240; 0207/10
R30, R31, R32, R33, R34, R35, R36, R37, R38, R39, R40, R41, R42, R43, R44, R45, R46, R47, R48, R49, R50, R51, R52, R53, R54, R55, R56, R57, R58, R59, R60, R61, R62, R63, R64, R65, R66, R67, R68, R69, R70, R71: 10k; 0207/10
S4: 10-XX; B3F-10XX
SCIENCE: DUE(BOTTOMONLY)
SCI_ADD: SWS004; SMS-004
SCI_SENSORS: MOLEX; 5566-4
TX2HEADER: MA10-2
TX2_POWER: 5566-2
VIN: MOLEX; 5566-4

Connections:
ARM_ADD_1: ARM.42, ARM_ADD.8, R60.1
ARM_ADD_2: ARM.43, ARM_ADD.7, R61.1
ARM_ADD_3: ARM.44, ARM_ADD.6, R62.1
ARM_ADD_4: ARM.45, ARM_ADD.5, R63.1
ARM_ENC1_A: ARM_ENCODERS.1, R1.1, R47.2
ARM_ENC1_B: ARM_ENCODERS.2, R2.1, R48.2
ARM_ENC2_A: ARM_ENCODERS.3, R3.1, R49.2
ARM_ENC2_B: ARM_ENCODERS.4, R4.1, R50.2
ARM_ENC3_A: ARM_ENCODERS.5, R5.1, R51.2
ARM_ENC3_B: ARM_ENCODERS.6, R6.1, R52.2
ARM_ENC4_A: ARM_ENCODERS.7, R7.1, R53.2
ARM_ENC4_B: ARM_ENCODERS.8, R8.1, R54.2
ARM_ENC5_A: ARM_ENCODERS.9, R9.1, R55.2
ARM_ENC5_B: ARM_ENCODERS.10, R10.1, R56.2
ARM_ENC6_A: ARM_ENCODERS.11, R11.1, R57.2
ARM_ENC6_B: ARM_ENCODERS.12, R12.1, R58.2
BATTERY_IN: C1.+, C2.2, TX2_POWER.1, VIN.1
DRIVE_ADD_1: DRIVE.42, DRIVE_ADD.8, R64.1
DRIVE_ADD_2: DRIVE.43, DRIVE_ADD.7, R65.1
DRIVE_ADD_3: DRIVE.44, DRIVE_ADD.6, R66.1
DRIVE_ADD_4: DRIVE.45, DRIVE_ADD.5, R67.1
DRIVE_ENC1_A: DRIVE_ENCODERS.1, R13.1, R30.2
DRIVE_ENC1_B: DRIVE_ENCODERS.2, R14.1, R36.2
DRIVE_ENC2_A: DRIVE_ENCODERS.3, R15.1, R37.2
DRIVE_ENC2_B: DRIVE_ENCODERS.4, R16.1, R38.2
DRIVE_ENC3_A: DRIVE_ENCODERS.5, R17.1, R39.2
DRIVE_ENC3_B: DRIVE_ENCODERS.6, R18.1, R40.2
DRIVE_ENC4_A: DRIVE_ENCODERS.7, R19.1, R41.2
DRIVE_ENC4_B: DRIVE_ENCODERS.8, R20.1, R42.2
DRIVE_ENC5_A: DRIVE_ENCODERS.9, R21.1, R43.2
DRIVE_ENC5_B: DRIVE_ENCODERS.10, R22.1, R44.2
DRIVE_ENC6_A: DRIVE_ENCODERS.11, R23.1, R45.2
DRIVE_ENC6_B: DRIVE_ENCODERS.12, R24.1, R46.2
ENC1_A: DRIVE.22, ENC7.7 (VO1)
ENC1_ARM_A: ARM.22, ENC1.7 (VO1)
ENC1_ARM_B: ARM.23, ENC1.6 (VO2)
ENC1_B: DRIVE.23, ENC7.6 (VO2)
ENC2_A: DRIVE.24, ENC8.7 (VO1)
ENC2_ARM_A: ARM.24, ENC2.7 (VO1)
ENC2_ARM_B: ARM.25, ENC2.6 (VO2)
ENC2_B: DRIVE.25, ENC8.6 (VO2)
ENC3_A: DRIVE.26, ENC9.7 (VO1)
ENC3_ARM_A: ARM.26, ENC3.7 (VO1)
ENC3_ARM_B: ARM.27, ENC3.6 (VO2)
ENC3_B: DRIVE.27, ENC9.6 (VO2)
ENC4_A: DRIVE.28, ENC10.7 (VO1)
ENC4_ARM_A: ARM.28, ENC4.7 (VO1)
ENC4_ARM_B: ARM.29, ENC4.6 (VO2)
ENC4_B: DRIVE.29, ENC10.6 (VO2)
ENC5_A: DRIVE.30, ENC11.7 (VO1)
ENC5_ARM_A: ARM.30, ENC5.7 (VO1)
ENC5_ARM_B: ARM.31, ENC5.6 (VO2)
ENC5_B: DRIVE.31, ENC11.6 (VO2)
ENC6_A: DRIVE.32, ENC12.7 (VO1)
ENC6_ARM_A: ARM.32, ENC6.7 (VO1)
ENC6_ARM_B: ARM.33, ENC6.6 (VO2)
ENC6_B: DRIVE.33, ENC12.6 (VO2)
GND: ARM.5V_ICSP, ARM.GND1, ARM.GND_1, ARM.GND_2, ARM.GND_A, ARM.GND_B, ARM_ENCODERS.19, ARM_ENCODERS.20, ARM_ENCODERS.21, ARM_ENCODERS.22, ARM_ENCODERS.23, ARM_ENCODERS.24, C1.-, C2.1, C3.2, C4.1, C5.-, C6.2, C7.2, C8.2, C9.2, C10.2, C11.2, C12.2, C13.2, C14.2, C15.2, C16.2, C17.2, C18.2, C19.2, DRIVE.5V_ICSP, DRIVE.GND1, DRIVE.GND_1, DRIVE.GND_2, DRIVE.GND_A, DRIVE.GND_B, DRIVE_ENCODERS.19, DRIVE_ENCODERS.20, DRIVE_ENCODERS.21, DRIVE_ENCODERS.22, DRIVE_ENCODERS.23, DRIVE_ENCODERS.24, ENC1.2 (C1), ENC1.3 (C2), ENC1.5 (GND), ENC2.2 (C1), ENC2.3 (C2), ENC2.5 (GND), ENC3.2 (C1), ENC3.3 (C2), ENC3.5 (GND), ENC4.2 (C1), ENC4.3 (C2), ENC4.5 (GND), ENC5.2 (C1), ENC5.3 (C2), ENC5.5 (GND), ENC6.2 (C1), ENC6.3 (C2), ENC6.5 (GND), ENC7.2 (C1), ENC7.3 (C2), ENC7.5 (GND), ENC8.2 (C1), ENC8.3 (C2), ENC8.5 (GND), ENC9.2 (C1), ENC9.3 (C2), ENC9.5 (GND), ENC10.2 (C1), ENC10.3 (C2), ENC10.5 (GND), ENC11.2 (C1), ENC11.3 (C2), ENC11.5 (GND), ENC12.2 (C1), ENC12.3 (C2), ENC12.5 (GND), GPS.4, IMU1.4, IMU2.4, LIMIT_4.2 (C1), LIMIT_4.3 (C2), LIMIT_4.5 (GND), LIMIT_5.2 (C1), LIMIT_5.3 (C2), LIMIT_5.5 (GND), LIMIT_6.2 (C1), LIMIT_6.5 (GND), R30.1, R31.1, R32.1, R33.1, R34.1, R35.1, R36.1, R37.1, R38.1, R39.1, R40.1, R41.1, R42.1, R43.1, R44.1, R45.1, R46.1, R47.1, R48.1, R49.1, R50.1, R51.1, R52.1, R53.1, R54.1, R55.1, R56.1, R57.1, R58.1, R59.2, R60.2, R61.2, R62.2, R63.2, R64.2, R65.2, R66.2, R67.2, R68.2, R69.2, R70.2, R71.2, SCIENCE.5V_ICSP, SCIENCE.GND1, SCIENCE.GND_1, SCIENCE.GND_2, SCIENCE.GND_A, SCIENCE.GND_B, SCI_SENSORS.4, TX2HEADER.16, TX2HEADER.18, TX2HEADER.19, TX2HEADER.20, TX2_POWER.2, VIN.3, VIN.4
LIMIT_1: ARM.37, LIMIT_4.7 (VO1)
LIMIT_2: ARM.38, LIMIT_4.6 (VO2)
LIMIT_3: ARM.39, LIMIT_5.7 (VO1)
LIMIT_4: ARM.40, LIMIT_5.6 (VO2)
LIMIT_5: ARM.41, LIMIT_6.7 (VO1)
LIM_1: LIMIT_SWITCHES.6, R25.1, R31.2
LIM_2: LIMIT_SWITCHES.7, R26.1, R32.2
LIM_3: LIMIT_SWITCHES.8, R27.1, R33.2
LIM_4: LIMIT_SWITCHES.9, R28.1, R34.2
LIM_5: LIMIT_SWITCHES.10, R29.1, R35.2
unnamed: ARM_PWM.7, ARM_PWM.8, ARM_PWM.9, ARM_PWM.10, ARM_PWM.11, ARM_PWM.12
unnamed: ENC1.1 (A1), R1.2
unnamed: ENC1.4 (A2), R2.2
unnamed: ENC2.1 (A1), R3.2
unnamed: ENC2.4 (A2), R4.2
unnamed: ENC3.1 (A1), R5.2
unnamed: ENC3.4 (A2), R6.2
unnamed: DRIVE_PWM.7, DRIVE_PWM.8, DRIVE_PWM.9, DRIVE_PWM.10, DRIVE_PWM.11, DRIVE_PWM.12
unnamed: ENC4.1 (A1), R7.2
unnamed: ENC4.4 (A2), R8.2
unnamed: ENC5.1 (A1), R9.2
unnamed: ENC5.4 (A2), R10.2
unnamed: ENC6.1 (A1), R11.2
unnamed: ENC6.4 (A2), R12.2
unnamed: LIMIT_4.1 (A1), R25.2
unnamed: SCIENCE.SDA1, SCI_SENSORS.2
unnamed: LIMIT_4.4 (A2), R26.2
unnamed: SCIENCE.SCL1, SCI_SENSORS.1
unnamed: LIMIT_5.1 (A1), R27.2
unnamed: LIMIT_5.4 (A2), R28.2
unnamed: LIMIT_6.1 (A1), R29.2
unnamed: ENC7.1 (A1), R13.2
unnamed: ENC7.4 (A2), R14.2
unnamed: ENC8.1 (A1), R15.2
unnamed: ENC8.4 (A2), R16.2
unnamed: ENC9.1 (A1), R17.2
unnamed: ENC9.4 (A2), R18.2
unnamed: ENC10.1 (A1), R19.2
unnamed: ENC10.4 (A2), R20.2
unnamed: ENC11.1 (A1), R21.2
unnamed: ENC11.4 (A2), R22.2
unnamed: ENC12.1 (A1), R23.2
unnamed: ENC12.4 (A2), R24.2
PWM_ARM_J1: ARM.2, ARM_PWM.1
PWM_ARM_J2: ARM.3, ARM_PWM.2
PWM_ARM_J3: ARM.4, ARM_PWM.3
PWM_ARM_J4: ARM.5, ARM_PWM.4
PWM_ARM_J5: ARM.6, ARM_PWM.5
PWM_ARM_J6: ARM.7, ARM_PWM.6
PWM_DRIVE_1: DRIVE.2, DRIVE_PWM.1
PWM_DRIVE_2: DRIVE.3, DRIVE_PWM.2
PWM_DRIVE_3: DRIVE.4, DRIVE_PWM.3
PWM_DRIVE_4: DRIVE.5, DRIVE_PWM.4
PWM_DRIVE_5: DRIVE.6, DRIVE_PWM.5
PWM_DRIVE_6: DRIVE.7, DRIVE_PWM.6
RESET: ARM.RESET, DRIVE.RESET, R59.1, S4.1 (S), SCIENCE.RESET, TX2HEADER.15
SCI_ADD_1: R68.1, SCIENCE.42, SCI_ADD.8
SCI_ADD_2: R69.1, SCIENCE.43, SCI_ADD.7
SCI_ADD_3: R70.1, SCIENCE.44, SCI_ADD.6
SCI_ADD_4: R71.1, SCIENCE.45, SCI_ADD.5
SCL: ARM.SCL, DRIVE.SCL, IMU1.2, IMU2.2, SCIENCE.SCL, TX2HEADER.11
SDA: ARM.SDA, DRIVE.SDA, IMU1.1, IMU2.1, SCIENCE.SDA, TX2HEADER.12
STEPPER_DIR: ARM.35, ARM_STEPPER.2
STEPPER_ENA: ARM.34, ARM_STEPPER.1
STEPPER_PUL: ARM.36, ARM_STEPPER.3
UART0_RX: GPS.1, TX2HEADER.4
UART0_TX: GPS.2, TX2HEADER.3
UART1_RX: TX2HEADER.6
UART1_TX: TX2HEADER.5
VCC: ARM.VIN, ARM_ADD.1, ARM_ADD.2, ARM_ADD.3, ARM_ADD.4, ARM_ENCODERS.13, ARM_ENCODERS.14, ARM_ENCODERS.15, ARM_ENCODERS.16, ARM_ENCODERS.17, ARM_ENCODERS.18, ARM_STEPPER.4, ARM_STEPPER.5, ARM_STEPPER.6, C3.1, C4.2, C5.+, C6.1, C7.1, C8.1, C9.1, C10.1, C11.1, C12.1, C13.1, C14.1, C15.1, C16.1, C17.1, C18.1, C19.1, DRIVE.VIN, DRIVE_ADD.1, DRIVE_ADD.2, DRIVE_ADD.3, DRIVE_ADD.4, DRIVE_ENCODERS.13, DRIVE_ENCODERS.14, DRIVE_ENCODERS.15, DRIVE_ENCODERS.16, DRIVE_ENCODERS.17, DRIVE_ENCODERS.18, ENC1.8 (VCC), ENC2.8 (VCC), ENC3.8 (VCC), ENC4.8 (VCC), ENC5.8 (VCC), ENC6.8 (VCC), ENC7.8 (VCC), ENC8.8 (VCC), ENC9.8 (VCC), ENC10.8 (VCC), ENC11.8 (VCC), ENC12.8 (VCC), LIMIT_4.8 (VCC), LIMIT_5.8 (VCC), LIMIT_6.8 (VCC), LIMIT_SWITCHES.1, LIMIT_SWITCHES.2, LIMIT_SWITCHES.3, LIMIT_SWITCHES.4, LIMIT_SWITCHES.5, S4.3, SCIENCE.VIN, SCI_ADD.1, SCI_ADD.2, SCI_ADD.3, SCI_ADD.4, VIN.2
VDD: GPS.3, IMU1.3, IMU2.3, SCI_SENSORS.3, TX2HEADER.1

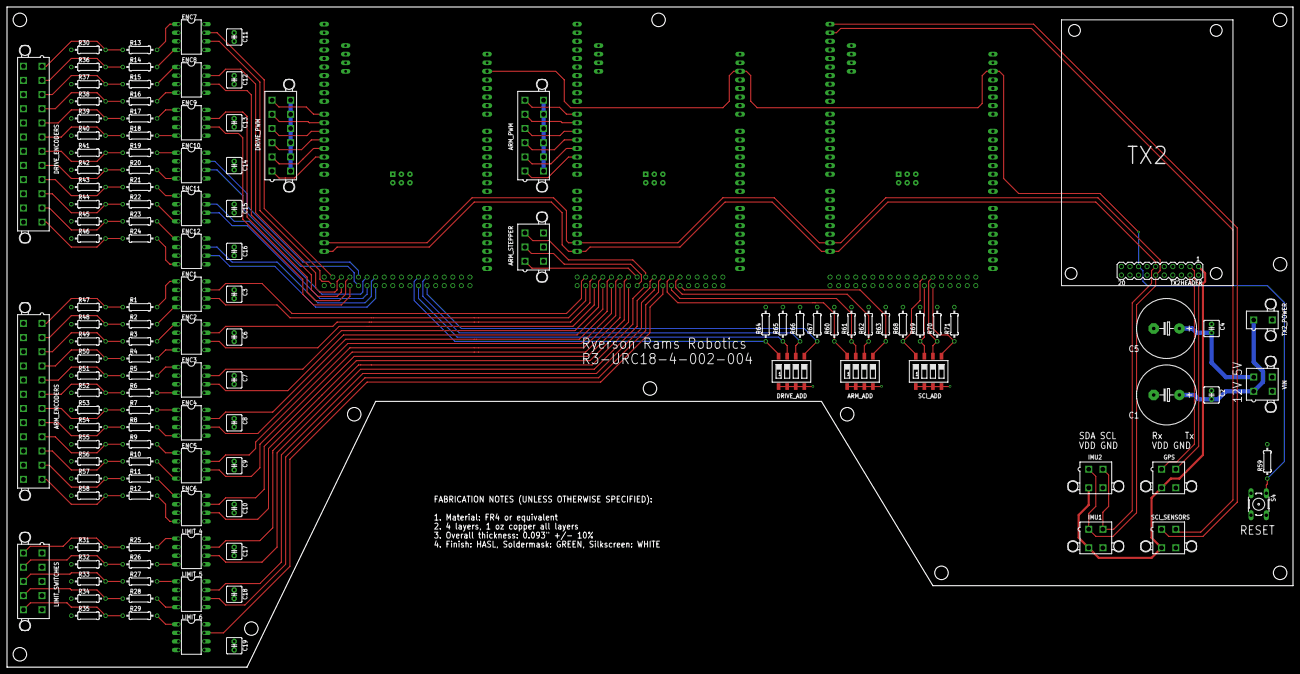
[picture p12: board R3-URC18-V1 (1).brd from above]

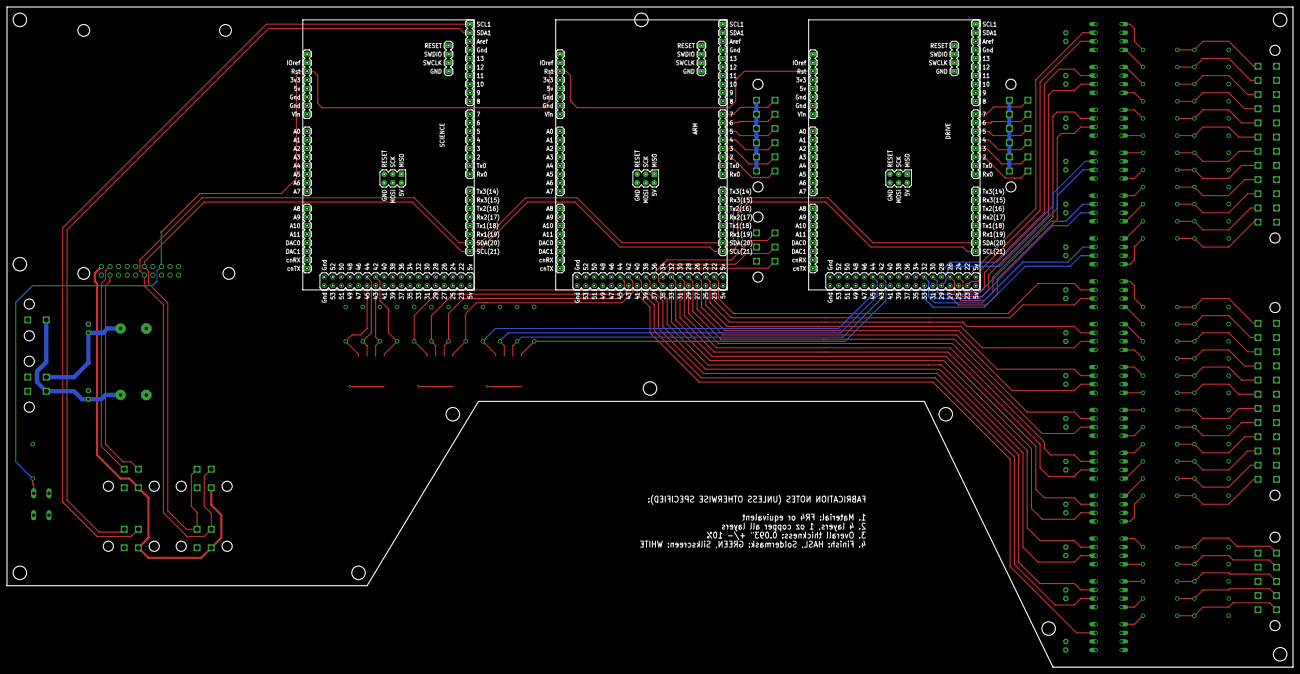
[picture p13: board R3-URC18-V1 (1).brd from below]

Board: 4 copper layers, 381.0 x 195.6 mm, 125 parts (3 on the bottom side), 127 nets.

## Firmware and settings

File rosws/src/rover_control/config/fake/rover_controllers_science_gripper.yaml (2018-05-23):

arm_manual_controller:
  type: effort_controllers/JointGroupPositionController
  joints:
    - arm_slide_pole_to_arm_slider_unit
    - arm_slider_unit_to_arm_xy_pole
    - science_crossbar_to_science_sensors

  arm_slider_unit_to_arm_xy_pole:
    pid: {p: 270.0, d: 20, i: 0, i_clamp: 1}
  science_crossbar_to_science_sensors:
    pid: {p: 170.0, d: 40, i: 0, i_clamp: 1}
  arm_slide_pole_to_arm_slider_unit:
    pid: {p: 4075.0, d: 0, i: 0, i_clamp: 0}

drill_controller:
  type: effort_controllers/JointEffortController
  joint: arm_inner_to_science_drill

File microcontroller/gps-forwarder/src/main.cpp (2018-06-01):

#include <Arduino.h>
#include <Wire.h>

class GPSTracker {
public:
    GPSTracker() {
        len = 0;
        datas = reinterpret_cast<uint8_t *>(malloc(0));
        strs = reinterpret_cast<unsigned char **>(malloc(0));
    }

    void recordDatum(uint8_t dlen, unsigned char * d) {
        push();
        *(datas + (len - 1)) = dlen;
        *(strs + (len - 1)) = d;
    }

    uint8_t topLen() {
        return *(datas + (len - 1));
    }

    unsigned char * popStr() {
        unsigned char * top = *(strs + (len - 1));
        pop();
        return top;
    }

    bool ok() {
        return len > 0;
    }
private:
    void push() {
        len+=1;
        datas = reinterpret_cast<uint8_t *>(realloc(datas, len * sizeof(uint8_t)));
        strs = reinterpret_cast<unsigned char **>(realloc(strs, len*sizeof(unsigned char *)));
    }

    void pop() {
        len-=1;
        datas = reinterpret_cast<uint8_t *>(realloc(datas, len * sizeof(uint8_t)));
        strs = reinterpret_cast<unsigned char **>(realloc(strs, len*sizeof(unsigned char *)));
    }

    uint8_t *datas;
    uint16_t len = 0;
    unsigned char ** strs;
};

GPSTracker gps;
const int ADDRESS = 0x48;

int context = 0;

void onRequest() {
    if (gps.ok()) {
        if (context == 0) {
            Wire.write(0x01);
            context += 1;
        }
        else if (context == 1) {
            uint8_t length = gps.topLen();
            Wire.write(length);
            context += 1;
        }
        else if (context == 2) {
            uint8_t length = gps.topLen();
            unsigned char *stringy_the_beef = gps.popStr();
            Wire.write(reinterpret_cast<uint8_t *>(stringy_the_beef), length);
            free(stringy_the_beef);
            context = 0;
        }
    }
    else {
        Wire.write(0x00);
        context = 0;
    }
}

void setup() {
    Serial.begin(9600);
    Wire.begin(ADDRESS);
    Wire.onRequest(onRequest);
}

void loop() {
    String amt = Serial.readStringUntil('\n');
    uint8_t bufLen = amt.length();
    if (bufLen < 3) return;
    char * buffer = reinterpret_cast<char *>(malloc(bufLen));
    amt.toCharArray(buffer, bufLen);
    gps.recordDatum(bufLen, reinterpret_cast<unsigned char *>(buffer));
}

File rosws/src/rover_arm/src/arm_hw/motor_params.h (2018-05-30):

//
// Created by matthew on 5/9/18.
//

#ifndef ROVERARMHW_MOTOR_PARAMS_H
#define ROVERARMHW_MOTOR_PARAMS_H

namespace rover_arm {
    const int MOTOR_MID = 1500;
    const int MOTOR_OFFSET = 900;

    const double MOTOR_EXERTED_EFFORT = 100;
    const double TICKS_PER_REVOLUTION = 3415.92;

    const double MOTOR328_EXERTED_EFFORT = 78.7278290794663;
    const double MOTOR328_TICKS_PER_REVOLUTION = 1288.848;
}

#endif //ROVERARMHW_MOTOR_PARAMS_H

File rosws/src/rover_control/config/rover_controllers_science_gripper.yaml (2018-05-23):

arm_manual_controller:
  type: effort_controllers/JointGroupPositionController
  joints:
    - arm_slide_pole_to_arm_slider_unit
    - arm_slider_unit_to_arm_xy_pole
    - science_crossbar_to_science_sensors

  arm_slider_unit_to_arm_xy_pole:
    pid: {p: 170.0, d: 15, i: 0, i_clamp: 1}
  science_crossbar_to_science_sensors:
    pid: {p: 200.0, d: 0.5, i: 0, i_clamp: 1}
  arm_slide_pole_to_arm_slider_unit:
    pid: {p: 4075.0, d: 120, i: 0, i_clamp: 1}

drill_controller:
  type: effort_controllers/JointEffortController
  joint: arm_inner_to_science_drill

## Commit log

2017-08-04 New stuff with urdf
    Also did some work on the setup script, thought i'd push it up
    [rover.urdf, wheel.xacro]
2017-08-04 working gazebo config w/ simple rover
    [arm.xacro, rover.urdf, rover.xacro.urdf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]
2017-08-06 holy code dump. also moveit works now and there's an arm
    [arm.xacro, fake_controllers.yaml, joint_limits.yaml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]
2017-08-06 sort of works? might need to tune pids more though
    [arm.xacro, controllers.yaml]
2017-08-07 add documentation, might of also added the zed (might)
    [arm.xacro, joint_limits.yaml, rover.xacro.urdf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]
2017-08-22 add base encoder project
2017-08-22 get master to a point where i'd call it "working correctly" so we can get branching started
    [rover_controllers_fake.yaml]
2017-09-07 move moveit away
    [controllers.yaml, fake_controllers.yaml, joint_limits.yaml]
2017-09-26 TRAC-IK (#3)
    * start tracik
    (yes i know i took forever i was busy ok?)
    * basic header stuffs
    need to do a bit more reading
    use zsh!
    * go fish
    * working ik
    * AAAHAHADHAHAAHAAHAHAHAHHAHAHAHHAH
    * fix js
    * new docs
    * oops
    [rover_controllers_fake.yaml]
2017-09-28 All pcbs (#5)
    * Added Encoder Stuffs
    * fixed stuff that mini matt made apparent to me
    * v1.0
    * armboard Rev 2
    * drive board v1
    * tx1 board completed
    [Encoder Connector.sch, PW Connector.sch, PWM Connector.sch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]
2017-09-28 Start new arm
    including new stars like:
    - the poles
    - the box
    - the encap
    and returning players like:
    - the gripper
    [arm.xacro, rover.xacro.urdf, sensors.xacro]
2017-10-04 new ARM!!!!!
    [arm.xacro, rover_controllers_fake.yaml]
2017-10-04 better naming
    [arm.xacro]
2017-10-27 servo test
2017-10-27 moar docs
    [rover_controllers.yaml]
2017-10-31 Simple drive+ros control (#4)
    * create simple drive
    * simple drive teleop + launch
    * fix launch file + new launch file
    should be done with simple drive now (i hope).
    currently tuned to ramsbot configuration!
    * compiles correctly (clion y u miss errors?)
    * squelch warnings with streams
    * sync
    * new i2c library
    * changes
    * done?
    * changes
    * change params
    * fix some strings
    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
    [rover_controllers.yaml, rover_controllers_fake.yaml]
2017-11-01 start robot_localization
    good working odom
    [sensors.xacro]
2017-11-23 add more stuff to make auton easier
    [wheel.xacro]
2017-11-28 something yay it kind of works but stupid stuff makes it doesn't
    [rover_controllers_fake.yaml, wheel.xacro]
2017-12-19 extra things
    [wheel.xacro]
2018-01-12 create stereo camera
2018-01-12 Wheel friction fix (#9)
    * Remove simple_drive.launch
    It was just a poop anyways
    * yippe yooooooo!
    in other words, it functions now
    [wheel.xacro]
2018-01-18 Randomized blabla
    [arm.xacro]
2018-01-18 yippe yooooooo!
    (cherry picked from commit a7708cd)
    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
    [wheel.xacro]
2018-01-19 pretty much functioning!
    [rover.xacro.urdf, rover_controllers_fake.yaml, sensors.xacro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]
2018-01-23 stage 1 of new docs:
    add gazebo (As i modified it here)
    reformat to make it uniform
2018-01-25 more odometry locations, added a laser to the urdf (probably will be unused)
    added parameters to the max wheel speed to prepare for fixing proper values for real rover
    these values need fixing for actual rover operations
    [rover_controllers_fake.yaml, sensors.xacro]
2018-01-26 Rover cameras (#10)
    * intial commit to usb_camea
    * dofus
    * add rotater
    * dofus
    * dofus
    * dofus
    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
2018-02-09 R3_IDON_O_TLIK_ENAMING_BRANCHES_LIKE_THIS_AAAA (#11)
    * Organizing
    * Does not work yet
    * Add pcbs to README
    * Create science_boards
    * Delete science_boards
    * Create read_me
    * Add files via upload
    * Create read_me
    * version one. Gabe plz check
    * fix hamza
    * Hamza & my PCBS
    * check this gabe
    * updated with dimensions and inline voltage isolator placement for DO circuit
    * updated with dust sensor
    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
    [Encoder Connector.sch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]
2018-02-15 calibrate stereo
2018-02-16 START ARM
2018-02-16 begin work on rover arm,
    [rover_controllers.yaml, rover_controllers_fake.yaml]
2018-02-16 more arm
    [arm.xacro]
2018-02-16 change urdf to have similar names to stereo cam
    [sensors.xacro]
2018-02-16 make it work with stereo & simulation (hopefully)
    [sensors.xacro]
2018-02-20 current version
    [arm.xacro, rover_controllers_fake.yaml]
2018-02-21 reformat arm to a better format
    [arm.xacro, normal_gripper.xacro, rover.xacro.urdf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]
2018-02-21 add science gripper
    [normal_gripper.xacro, science_gripper.xacro]
2018-02-21 add science controllers
    [rover_controllers_science_gripper.yaml]
2018-02-22 begin science arm
    [rover_controllers_normal_gripper.yaml, rover_controllers_science_gripper.yaml, science_gripper.xacro]
2018-02-22 tune pids better
    [rover_controllers_science_gripper.yaml, science_gripper.xacro]
2018-03-02 add various things
    [arm.xacro, science_gripper.xacro]
2018-03-03 change outdoor_world to support multiple grippers
    a sane commit message?
2018-03-17 start work on new stereo config
    [sensors.xacro, stereo.xacro]
2018-03-17 finish new stereo config (needs testing)
    [stereo.xacro]
2018-03-18 switch sim back over to stereo...
    [stereo.xacro]
2018-03-28 51 dollars for a new calibration...
    MONEY WELL SPENT!!!!
2018-04-03 fix urdf for stereo cameras
    [stereo.xacro]
2018-04-03 Stereo urdf (#12)
    * servo test
    * change back to victors!
    t
    * servo test
    * change back to victors!
    t
    * yay
    * ros_control drive
    controllers are working, testing of hardware is probably happening on saturday
    * docs v. 1
    * docs v. 2
    * docs v. 2.5
    * sumting
    * better naming
    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
    [arm.xacro, rover.xacro.urdf, rover_controllers_fake.yaml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]
2018-04-03 51 dollars for a new calibration...
    (cherry picked from commit a9eb967)
    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
2018-04-03 holy fuck
    [Encoder Connector.sch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]
2018-04-10 Uberfirmware split (#13)
    * move eml_uberdriver
    * almost done docs for eml_uberdriver
    WARNING: this will probably get moved out to rtd for a seperate system, but for now
    it is staying here
    * fix uberfirmware
    * update docs for arduino protocol to be pointing to eml_uberdriver
    * yes
    * add controller_diagnostics to wstool
    * start work on diagnostics
    needs:
    - diagnostics to be implemented (waiting on eml to merge)
    * 51 dollars for a new calibration...
    * yes
    * add controller_diagnostics to wstool
    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
    [rover_controllers.yaml]
2018-04-10 start toggle button (also made teleop support disabling)
2018-04-11 add toggle button
2018-04-12 wrong bloody frame id
    [tennis_ball.sdf]
2018-05-09 further change
    [rover_controllers.yaml]
2018-05-09 Fix incorrect behavior in drive_hw.
    Reflects upstream changes in eml_uberdriver.
    [hw_impl.cpp]
2018-05-09 start work on new arm software
    for test
    it'll work
    i promise
    no i dont
    neveer mind
    [normal_gripper.xacro]
2018-05-10 maybe working code for arm
    [arm.xacro, rover_controllers_normal_gripper.yaml]
2018-05-11 modify
    GABE WHY
    [rover_controllers_normal_gripper.yaml]
2018-05-11 yayyayayayaya
    why am i so tired
2018-05-12 add motor constants
    [arm.xacro, normal_gripper.xacro]
2018-05-12 2 is not wired?
2018-05-14 oOoOoOOOPS
    "Illegal bounds change ... offending layer is lines_layer"
    Well screw you too move_base
2018-05-15 Arm software (#14)
    SQUAAAAASH it and merge it
    woopeee
    * Start new arm
    * new ARM!!!!!
    * START ARM
    * begin work on rover arm,
    * more arm
    * stuff in progress
    * current version
    * asdf
    * reformat arm to a better format
    * add science gripper
    * add science controllers
    * reorg arm_hw
    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
    [arm.xacro, normal_gripper.xacro, rover.xacro.urdf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]
2018-05-16 start imugps
2018-05-16 add les units
    [arm.xacro, rover.xacro.urdf, sensors.xacro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]
2018-05-16 update imu posistion
    [sensors.xacro]
2018-05-20 fuckit 2: electric boogaloo
    [normal_gripper.xacro]
2018-05-20 it works?
    [normal_gripper.xacro, rover_controllers_normal_gripper.yaml]
2018-05-20 add gripper
2018-05-23 please stop annoying me
    [rover_controllers_normal_gripper.yaml]
2018-05-24 Arm software (#16)
    * begin science arm
    * tune pids better
    * begin as
    * asdf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
    [arm.xacro, normal_gripper.xacro, rover_controllers_normal_gripper.yaml]
2018-05-24 Arm software 2 (#17)
    * asd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
2018-05-24 failde attempt at a launch file
    [gps_forwarder.cpp]
2018-05-24 add rover.launch imus
2018-05-25 add camera controller code
2018-05-25 add swapper code (TODO: add default cameras)
2018-05-29 Revert "add"
    This reverts commit 27344e0e4d3e19c111b090619609b804c82ccae7.
    [normal_gripper.xacro]
2018-05-31 fix inverted
    [rover.xacro.urdf]
2018-05-31 Imus (#19)
    * test codez
    * FOR TESTIJNG
    * test2
    * test2
    * fix idiotic negation
    * something
    * AMAZING DOCUMENTATION
    * moar docs
    * bla
    * temp
    * fix
    * what
    * start robot_localization
    * unnessecary codeos
    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
    [ScienceDuino.brd, ScienceDuino.sch, arm.xacro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]
2018-05-31 Update master launch file
    We need imu + gps for tommorow
2018-05-31 Fix cameras
2018-06-01 Improve Camera Switcher (#21)
    * i got carried away
    * diagnostics for cameras
    * fixyboi
